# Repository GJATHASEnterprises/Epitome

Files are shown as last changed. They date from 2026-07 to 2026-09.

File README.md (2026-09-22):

# Epitome

**Charge everything. Touch nothing.**

[epitomecharge.com](https://epitomecharge.com)

---

## September 2026 lineup (canonical)

| Model | Price | Positioning | Enclosure | Lighting | MCU |
|---|---:|---|---|---|---|
| Step Walnut | $99 | Minimalist / wood-desk buyer | Black PETG base shell + wood-PLA top shell (sanded + Danish oil) | Single white status LED via 3 mm light pipe | Digispark-style ATtiny85 USB board |
| Step Obsidian | $109 | Gamer / battlestation buyer | Full CF-PETG (both shells) | WS2812B RGB glow lines, 8 LEDs per side (16 total) behind flush diffusers | Digispark-style ATtiny85 USB board |
| Outdoor Block Stone | $119 | Outdoor utility buyer | Sealed ASA body | Functional indicators only | Interlock controller |
| Outdoor Block Camo | $129 | Outdoor tactical aesthetic buyer | Sealed ASA body + camo finish | Functional indicators only | Interlock controller |

Notes (Sept-2026 planning estimates):
- Legacy material/process options were removed from the lineup.
- Customer pays shipping on all models.
- Step models include a 65W GaN brick, one 1 m USB-C input cable, and one USB-C output-device cable in-box.
- Step power configuration: 20W magnetic phone + up-to-15W second-device zone + 5W watch zone + 15W USB-C output (up to 60W total system claim).

## Source of truth docs

- `docs/launch-plan.md`
- `docs/technical-readouts/step-walnut.md`
- `docs/technical-readouts/step-obsidian.md`
- `docs/technical-readouts/outdoor-block-stone.md`
- `docs/technical-readouts/outdoor-block-camo.md`
- `docs/production-plan.md`
- `docs/budget-plan.md`
- `docs/marketing-plan.md`
- `docs/design-brief-step.md`
- `docs/assembly-guide.md`

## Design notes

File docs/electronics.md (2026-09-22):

# Epitome Step — Electronics Reference

Both models share the same beginner-friendly easy-connect electronics architecture. The only model differences are lighting hardware and the Obsidian rear mode button.

---

## Shared schematic overview

```
65W GaN brick
        │
        ▼
USB-C PD input receptacle (rear X=40)
        │
        ▼
PD input trigger board (20V negotiated input)
        │
        ▼
20V distribution PCB / block
        ├──→ 12V screw-terminal buck converter ──→ Qi2 20W TX (Zone 1)
        │                                      └──→ Qi TX up-to-15W (Zone 2)
        ├──→ 5V screw-terminal buck converter ──→ Watch TX coil (Zone 3)
        │                                      ├──→ Digispark-style ATtiny85 USB board
        │                                      └──→ Lighting harness
        └──→ USB-C PD 15W trigger board (rear output)
```

---

## Zone-by-zone power paths

### Zone 1 — Phone (Qi2 20W)
- Feed: 12V branch
- TX module: Qi2 20W magnetic module
- Protection: polyfuse (1.5A) + NTC + hardwired thermal cutoff
- Marketing language: "Qi2 magnetic charging — compatible with MagSafe-case iPhones and Qi2 Android phones"

### Zone 2 — Buds or second phone (up to 15W)
- Feed: **12V branch** (moved from 5V path)
- TX module: same $5.63 class TX as Zone 1 (non-magnetic placement)
- Protection: polyfuse (1.5A)
- Positioning language: "buds or a second phone — up to 15W"

### Zone 3 — Watch zone (5W)
- Feed: 5V branch
- TX: generic watch coil by default
- Important truth: generic watch coil does not charge Apple Watch without MFi-certified hardware

### USB-C output (rear)
- Trigger board: 15W-class output board
- Protection: polyfuse (~1A hold) + TVS diode
- Fuse basis: 15W at 20V is ~0.75A nominal

---

## Power budget (Sept-2026 planning)

| Load | Max power |
|---|---:|
| Zone 1 Qi2 TX | 20W |
| Zone 2 Qi TX | 15W |
| Zone 3 watch | 5W |
| USB-C output | 15W |
| ATtiny85 + lighting | ~1.5W |
| **Theoretical max** | **~56.5W** |
| **Marketing claim cap** | **Up to 60W total** |
| **Included brick** | **65W** |

The firmware soft cap is a detect-based heuristic only. When all zones are active, Zone 2 drops to a low-power profile. USB-C branch current is not directly measured by firmware.

---

## Safety systems

| System | Purpose |
|---|---|
| Polyfuse Zone 1 | Overcurrent protection on Zone 1 TX |
| NTC thermistor Zone 1 | Feeds TX thermal protection path |
| Thermal cutoff Zone 1 | Hard cutoff above thermal threshold |
| Polyfuse Zone 2 | Overcurrent on Zone 2 TX |
| Polyfuse Zone 3 | Overcurrent on watch coil |
| 1A hold polyfuse + TVS on USB-C output | Overcurrent + ESD on output branch |

---

## Hard sourcing and compliance rules

- All TX modules must have verifiable module-level FCC IDs.
- Battery module rules (UN38.3 + UL docs) apply to Outdoor Block gating before sourcing.

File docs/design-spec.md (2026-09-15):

# Epitome Step — Physical Design Specification (Sept 2026)

## Envelope targets

- Footprint and tier envelope are finalized from measured modules and CAD lock review.
- Use the measurement-order workflow and dimensional lock process defined in project planning docs before freezing STL/STEP outputs.
- Corner radii target: 6–8 mm external.

## Material split

| Part | Walnut | Obsidian |
|---|---|---|
| Base shell | Black PETG | CF-PETG |
| Top shell | Wood-PLA (oiled) | CF-PETG |
| Lighting | White light pipe status LED | Recessed WS2812B side glow lines |
| MCU | Digispark-style ATtiny85 USB board | Digispark-style ATtiny85 USB board |

## Hard constraints

- Coil window ≤1.5 mm above each TX coil.
- M3 insert bosses and wiring channels integrated into shell geometry.
- Rear USB-C input recess and strain-relief path required.

For dimensions and measurements to lock before final CAD, use `docs/design-brief-step.md`.

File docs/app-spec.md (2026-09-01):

# Epitome Step — Future Features (Batch 2+)

**No app in Batch 1.** The ATtiny85 in Batch 1 handles everything locally. No BLE, no Wi-Fi, no app.

This document captures ideas for future batches. Nothing here is on the roadmap yet.

---

## Why no app in Batch 1

1. **Complexity kills Batch 1.** Adding app connectivity (ESP32, BLE pairing, iOS app) would double the electronics cost and triple the firmware work. Not justified for 10 units.
2. **Most users don't want an app for a charger.** Plug in and charge. The simpler it is, the better the product.
3. **The ATtiny85 is sufficient.** LED control, night mode, soft cap — all done without any wireless.

---

## Future ideas — Obsidian RGB app control

If there's demand for it, the Obsidian model could add a BLE module (ESP32-C3 or nRF52840) to allow app-based colour control:

- Choose any colour, not just the 8 presets
- Schedule night mode to actual clock time
- Per-zone LED brightness (e.g. dim Zone 2 if no buds detected)
- RGB mode sync with music (requires phone microphone access — complicated)

This would require replacing the ATtiny85 with a more capable MCU and adding a BLE antenna. Estimated additional cost: $4–6 per unit.

---

## Future ideas — zone scheduling

- Set specific zones to turn on/off at set times (e.g., disable Zone 1 phone charging after midnight)
- Use BLE-synced real-time clock instead of ATtiny85 timer

---

## Future ideas — zone toggles

- Physical or app-controlled toggle to disable a zone
- Useful for power management if user only has phone + watch (disable Zone 2)

---

## What to do before building any of this

1. Finish Batch 1 and ship it
2. Ask customers if they want an app
3. If > 50% say yes, prototype a BLE version for Batch 3
4. Keep Walnut as app-free — the Walnut buyer does not want an app for their charger

---

## What is explicitly NOT planned

- Voice control (Alexa/Google — unnecessary complexity)
- USB data transfer (charging only — USB-C ports are power-only PD)
- Display / screen on dock (adds cost, adds failure mode)
- Battery / UPS mode (too complex, too expensive)
- Laptop Qi charging (not in Qi/Qi2 spec at useful wattage)

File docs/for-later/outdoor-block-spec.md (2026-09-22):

# Epitome Outdoor Block — Concept Spec (FOR LATER)

**Status:** Concept. Gated behind Step Batch 1 success + reserve gate.

## Models and pricing

| Model | Price | Positioning |
|---|---:|---|
| Outdoor Block Stone | $119 | rugged neutral finish |
| Outdoor Block Camo | $129 | rugged camo finish |

## Tariffed BOM alignment (Sept 2026)

All China-sourced electronics use 25% Section 301 pricing. Reference: `docs/technical-readouts/outdoor-block-stone.md` and `docs/technical-readouts/outdoor-block-camo.md`.

| Part | Tariffed cost |
|---|---:|
| Certified 20,000 mAh PD bank | $22.50 |
| 20W magnetic phone TX | $7.50 |
| Zone 2 Qi TX module (up-to-15W class) | $5.63 |
| IP67 panel USB-C + cap | $4.00 |
| Interlock + sensors + harness | $7.30 |
| ASA/TPU enclosure + hardware | $8.00 |
| Camo process adder (Camo only) | $3.50 |
| Packaging/consumables | $0.50 |

Resulting build targets:
- **Stone:** ~$53.30 → net ~ $34/sale at $119
- **Camo:** ~$56.80 → net ~ $39/sale at $129

## Gates before spending reserve

- [ ] Step Batch 1 sold through (≥3 paid units)
- [ ] LLC + product liability insurance active
- [ ] Certified battery module source confirmed
- [ ] Prototype passes immersion/drop/thermal/runtime/interlock gates

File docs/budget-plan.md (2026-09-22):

# Epitome — Budget Plan (Sept 2026 planning estimates)

## Capital constraint

- Total available capital now: **~$2,000**.
- Operating rule: phase-gated launch from `docs/launch-plan.md` (demand-first, compliance-second, inventory-last).

## Startup costs (Step launch envelope)

These costs were missing from older parts-only planning and must be tracked up front:

| Startup item | Estimate | Notes |
|---|---:|---|
| FCC testing (good path with verifiable module FCC IDs) | ~$1,000–2,500 | Step Walnut + Obsidian share one test path |
| LLC formation | ~$50–150 | Must be active before selling |
| Year-1 general/product liability insurance | ~$500–1,050 | Range varies by carrier and disclosures |
| **Startup subtotal (compliance + legal + insurance)** | **~$1,550–3,700** | |

## Step launch total envelope

| Bucket | Estimate |
|---|---:|
| Prototype + tooling + CAD + measurement-order work | ~$800–900 |
| Startup subtotal (above) | ~$1,550–3,700 |
| **Total Step launch envelope** | **~$2,350–4,600** |

Because current capital is ~$2,000, execution must stay phase-gated and stop at each gate until funding and demand conditions are met.

## Unit economics reference (net-after-fees)

| Product | Build cost | Price | Net-after-fees |
|---|---:|---:|---:|
| Step Walnut | ~$48.63 | $99 | ~ $30–32/sale |
| Step Obsidian | ~$54.63 | $109 | ~ $34–38/sale |
| Outdoor Block Stone (gated) | ~$53.30 | $119 | ~ $34/sale |
| Outdoor Block Camo (gated) | ~$56.80 | $129 | ~ $39/sale |

## Hard sourcing gates

- Every TX module must have a verifiable module-level FCC ID.
- Outdoor Block battery modules must have verifiable UN38.3 and UL component docs.

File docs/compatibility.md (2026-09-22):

# Epitome Step — Device Compatibility

---

## Zone 1 — Phone (Qi2 magnetic, up to 20W)

| Device | Compatible | Notes |
|---|---|---|
| iPhone 13 and newer (with MagSafe-compatible case) | ✅ | Qi2 magnetic alignment |
| Qi2-enabled Android phones | ✅ | Qi2 alignment where supported |
| Other Qi-enabled phones | ✅ | Standard Qi fallback |

---

## Zone 2 — Buds / second phone (plain Qi, up to 15W)

| Device | Compatible | Notes |
|---|---|---|
| AirPods / Galaxy Buds / Pixel Buds (Qi case models) | ✅ | Typical draw is 2–5W |
| Qi-enabled second phone | ✅ | Non-magnetic placement |
| Non-Qi accessories | ❌ | Requires Qi receiver |

---

## Zone 3 — Watch zone

| Device | Compatible | Notes |
|---|---|---|
| Generic Qi watch devices | ✅ | With generic coil option |
| Apple Watch | ❌ by default | Requires separate MFi-certified module option |

Do not market Apple Watch support unless the MFi option is selected.

---

## USB-C output (rear)

| Port | Protocol | Compatible devices |
|---|---|---|
| USB-C output (15W) | USB-C PD class output | Phones, earbuds cases, small accessories, speakers |

In-box cables: 1 input cable + 1 output-device cable.

---

## Wording compliance

- Use: "Qi2 magnetic charging — compatible with MagSafe-case iPhones and Qi2 Android phones."
- Use: "up to 60W total."
- Avoid bare "MagSafe" as a standalone product claim.

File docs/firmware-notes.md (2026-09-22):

# Epitome Step — Firmware Notes (Digispark ATtiny85)

No ESP32. No BLE. No app. The Digispark-style ATtiny85 board handles LED control, heuristic load behavior, and night mode.

---

## Soft-cap context

The documented product-level claim is **"up to 60W total"**.

Current firmware is still detect-based:
- Zone 1 active estimate: +20W
- Zone 2 active estimate: up to +15W
- Zone 3 active estimate: +5W
- Lighting budget: up to ~1.5W
- USB-C output path is 15W-class, but firmware does not directly measure branch current.

When all zones are active, firmware shifts Zone 2 to a low-power profile. This is a heuristic behavior, not a measured closed-loop power controller.

---

## Watch-zone note

Default generic watch-coil path is not Apple Watch-compatible. Do not claim Apple Watch support in firmware-linked product docs unless MFi hardware is selected.

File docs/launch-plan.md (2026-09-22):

# Epitome — Master Launch Plan (Sept-2026 planning estimates)

This is the operating plan for launching Epitome with a hard capital limit of about **$2,000**.

## Core rules

- Total available capital: **~$2,000**.
- Every phase must fit inside that limit.
- Follow this order: **demand first, compliance second, inventory last**.
- Do **not** build sellable inventory before demand is proven and FCC authorization is complete.
- FCC rule reminder: advertising an unauthorized RF product as "for sale" is a violation. Waitlist pages must not take money or claim active sales.

## Phase 0 — Free verification week (~$0)

1. Ask Qi/Qi2 TX module vendors for module-level FCC IDs.
2. Verify each ID at: https://www.fcc.gov/oet/ea/fccid.
3. Ask the battery module vendor for UN38.3 + UL component docs for the future Outdoor Block.
4. Verify those battery docs directly with the issuing lab.
5. Request quotes from **3 FCC-recognized labs**.
6. Note in all quote requests: one FCC Step test covers both Walnut and Obsidian because electronics are identical; Stone and Camo can share one later test.

**Why this matters:**
- These free answers decide whether the near-term compliance bill lands around **~$1,000–1,500** (good path) or **~$4,000+** (bad path).

### Gate 0 → 1
Do not move to Phase 1 until these vendor and lab answers are documented.

## Phase 1 — Prototype + demand test (~$500–700)

1. Place a measurement order (~$35): one of each module from current docs.
2. Build only **2 prototypes total** (1 Walnut + 1 Obsidian), not 6.
3. Buy only essential setup/tooling (~$120).
4. Form LLC (~$50–150) before any selling activity.
5. Publish a free landing page + waitlist with prototype/renders.
6. Share in relevant communities (r/battlestations, r/functionalprint, etc.).
7. Waitlist page rules: no payments, no "for sale" claims.

### Gate 1 → 2
Move forward only if:
- Waitlist interest is meaningful (suggested threshold: **~100 signups**), **and**
- FCC quote path from Phase 0 remains favorable.

If demand is weak, pause. A max loss of about ~$700 means the demand test worked.

## Phase 2 — Compliance (~$1,000–2,500 if Phase 0 is favorable)

1. Run FCC verification testing for the Step platform (single test covering Walnut + Obsidian).
2. Activate year-1 general/product liability insurance (~$500–1,500).

### Gate 2 → 3
Do not proceed until FCC authorization is in hand.

## Phase 3 — Pre-order-funded production

1. Open paid pre-orders only after Phase 2 gate passes.
2. Build only what is sold.
3. Keep direct sales on own site (customer pays shipping) to avoid typical marketplace fees (~8–15% vs ~3% direct processing).

Sept-2026 planning economics after current Step optimizations:
- **Walnut build:** ~$48.63 → net about **$30–32** at $99.
- **Obsidian build:** ~$54.63 → net about **$34–38** at $109.

Compliance is a one-time toll; after prototypes, each additional unit is mostly BOM cost.

## Phase 4 — Outdoor Block (gated sequence, not cancelled)

Block remains gated until either:
- Step cumulative profit reaches **~$3,000**, or
- Block waitlist/pre-order interest reaches **~40 signups**.

Compliance floor (good path):
- **~$1,500–3,000** with FCC-ID'd modules + certified battery module docs + final FCC verification.
- Full UL 2056 end-product listing (~$15,000–30,000) is a **later scaling milestone** for Amazon/big retail, not required for legal direct sales.

Quality/failure-margin guidance:
- Keep **10–15% defect reserve**.
- Budget **1 sacrificial QC unit per batch** for destructive validation.
- Follow existing QC: immersion, 6-face drop, 25-cycle battery tests.

Li-ion shipping rules for Block:
- Ground only.
- UN3481.
- Battery installed in equipment.
- ≤100Wh (74Wh module qualifies).

## Risk register (plain-language)

1. **Cheap 65W brick risk**: the $9.50 target only stands if genuine UL/ETL/FCC docs check out and thermal-soak samples pass. If not, fall back to the $13.75 brick.
2. **Zone 2 geometry risk**: second phone/buds landing area must be validated in CAD before STL freeze.
3. **Dual-load thermal risk**: test Zone 1 + Zone 2 + USB-C use for hot spots and stability.
4. **Soft-cap firmware limitation**: current cap is heuristic detect-based behavior; no direct current measurement.
5. **Watch-zone compatibility risk**: generic watch coils do not charge Apple Watch without MFi hardware.
6. **Marketing wording risk**:
   - Say: "up to 60W total".
   - Say: "Qi2 magnetic charging — compatible with MagSafe-case iPhones".
   - Do not use bare "MagSafe" as a product claim.
   - Say: "IP67 — submersion-safe in shallow water".
   - Do not use unqualified "waterproof".

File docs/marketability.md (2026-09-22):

# Epitome Step — Market Positioning (Sept 2026 planning estimates)

## SKU narrative

| Model | Price | Buyer | Why it converts |
|---|---:|---|---|
| Step Walnut | $99 | Minimalist / wood-desk setups | Warm material story + clean status light |
| Step Obsidian | $109 | Gamer / battlestation setups | Matte carbon + RGB glow-line identity |

## Economics fit

- Walnut net: ~ $30–32/sale
- Obsidian net: ~ $34–38/sale
- Shipping is customer-paid; checkout clarity is part of conversion strategy.

## Message strategy

- Walnut copy: “minimal, warm, desk-first”.
- Obsidian copy: “dark battlestation, configurable RGB glow”.
- Technical trust language:
  - “Qi2 magnetic charging — compatible with MagSafe-case iPhones and Qi2 Android phones.”
  - “Up to 60W total.”
  - “Buds or second phone on Zone 2 (up to 15W, non-magnetic).”

## Watch-zone honesty requirement

- Generic watch coils do not charge Apple Watch.
- Do not depict Apple Watch charging unless an MFi module is selected.

For full cost stack and test gates, see `docs/production-plan.md` and `docs/technical-readouts/`.

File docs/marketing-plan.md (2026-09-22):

# Epitome — Marketing Plan (Sept 2026 planning estimates)

**Budget target: ~$400 paid marketing.** No paid spend until prototype photos and compliant launch wording are ready.

## Positioning

- **Step Walnut ($99):** minimalist / wood-desk buyer, warm premium aesthetic.
- **Step Obsidian ($109):** gamer / battlestation buyer, matte carbon + RGB glow-line identity.

## Channel allocation (~$400)

| Channel | Budget | Notes |
|---|---:|---|
| Etsy Ads (Walnut-led search terms) | $150 | Start low; kill if no traction |
| Meta/Instagram retargeting + short reels | $140 | Focus on creator-style demos |
| 2 gifted units to micro setup creators | ~$80 | Content + trust-building |
| Photo props/backdrop | $30 | Keep lean |
| **Reserve** | remainder | Includes trimmed Reddit test budget |

## Message guardrails

- Use: “Qi2 magnetic charging — compatible with MagSafe-case iPhones and Qi2 Android phones.”
- Use: “up to 60W total.”
- Use: “Zone 2 supports buds or a second phone (up to 15W, non-magnetic).”
- Do not use bare “MagSafe” as a product claim.
- Do not show Apple Watch in watch-zone visuals unless MFi hardware is selected.
- Never claim a product is for sale before FCC authorization is complete.

## Shipping note

Customer pays shipping. Run A/B copy tests only after compliance gates are met.

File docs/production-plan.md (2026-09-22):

# Epitome — Production Plan (Sept 2026 planning estimates)

## 1) Product lineup and build materials

- **Step Walnut ($99):** minimalist / wood-desk buyer. Black PETG base + wood-PLA top. Digispark-style ATtiny85. Single white status LED.
- **Step Obsidian ($109):** gamer / battlestation buyer. Full CF-PETG shells. Digispark-style ATtiny85. WS2812B RGB glow lines.
- **Outdoor Block Stone ($119) / Camo ($129):** 20W magnetic phone + 5–10W buds + 20W USB-C output (Batch 2 gated).

Authoritative per-model BOMs and QC gates live in `docs/technical-readouts/`.

## 2) Unit economics (customer pays shipping)

| Model | Build cost | Price | Net after fees/processing/defect reserve |
|---|---:|---:|---:|
| Step Walnut | ~$48.63 | $99 | ~ $30–32 / sale |
| Step Obsidian | ~$54.63 | $109 | ~ $34–38 / sale |
| Outdoor Block Stone | ~$53.30 | $119 | ~ $34 / sale |
| Outdoor Block Camo | ~$56.80 | $129 | ~ $39 / sale |

## 3) Sept-2026 tariffed reference prices (25% Section 301 on China-sourced electronics)

- Step Zone 1 TX: **$5.63**
- Step Zone 2 TX (same SKU class): **$5.63**
- Watch TX coil (generic): **$3.50 estimate**
- Step USB-C output trigger board (15W class): **$1.50**
- Step 65W GaN brick target: **$9.50** *(fallback $13.75 if cert docs fail checks)*
- Step cables (1 input + 1 output): **$3.00**
- Outdoor Block 20W magnetic TX: **$7.50**
- Outdoor Block IP67 USB-C: **$4.00**
- Outdoor Block 20,000 mAh certified PD bank: **$22.50**

## 4) Compliance and sourcing rules

- Every wireless TX module must have a verifiable module-level FCC ID.
- Outdoor Block battery modules must provide verifiable UN38.3 and UL component docs.
- Step Walnut + Obsidian share one FCC test path because electronics are identical.
- Outdoor Block Stone + Camo also share one test path later because electronics are identical.

## 5) Build sequence rules

- Do not build sellable inventory before demand is proven and FCC authorization is complete.
- Waitlist can be used before authorization, but must not collect payment or claim live sales.
- Operating gates and phase order are defined in `docs/launch-plan.md`.

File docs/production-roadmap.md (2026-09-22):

# Epitome — Production Roadmap (Sept 2026 planning estimates)

## Phase 0 — Free verification week (~$0)

- Verify FCC IDs for all candidate TX modules.
- Verify UN38.3 + UL component docs for Outdoor Block battery module.
- Collect 3 FCC-lab quotes.

Gate: do not continue until this verification package is complete.

## Phase 1 — Prototype + demand test (~$500–700)

- Build only 2 Step prototypes total: 1 Walnut + 1 Obsidian.
- Keep tooling essentials to about ~$120.
- Launch a free waitlist page (no payments, no "for sale" claims).

Gate: continue only if waitlist interest is meaningful (~100 signups suggested) and FCC quote path is favorable.

## Phase 2 — Compliance (~$1,000–2,500 good path)

- Run Step FCC authorization path.
- Activate year-1 general/product liability insurance.

Gate: FCC authorization must be in hand before paid pre-orders.

## Phase 3 — Pre-order-funded production

- Take paid orders only after compliance gate.
- Build only what is sold.
- Direct sales first to preserve margin.

## Phase 4 — Outdoor Block (gated)

- Keep Block gated until Step cumulative profit reaches ~$3,000 or Block waitlist/pre-order demand reaches ~40 signups.
- Good-path Block compliance floor: ~$1,500–3,000 with FCC-ID modules + certified battery docs + final verification.
- Full UL 2056 listing (~$15,000–30,000) is a later distribution milestone, not a launch requirement for legal direct sales.

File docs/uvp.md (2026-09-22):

# Epitome Step — Unique Value Proposition (Sept 2026 planning estimates)

## Positioning

- **Step Walnut ($99):** minimalist, warm desk aesthetic.
- **Step Obsidian ($109):** gamer battlestation aesthetic with RGB glow lines.

Both use the same charging architecture and include a 65W GaN brick, one USB-C input cable, and one USB-C output cable.

## Why it works

1. Distinct buyer fit instead of one compromise design.
2. Premium-looking materials at accessible pricing.
3. Practical charging setup: 20W magnetic phone, up-to-15W second zone, 5W watch zone, and 15W USB-C output.

## Product identity

- Walnut: black PETG base + wood-PLA top, sanded and oiled, single white status LED.
- Obsidian: full CF-PETG shell, WS2812B side glow lines, Digispark-style ATtiny85 USB mode control.

## Compliance and wording guardrails

- Use: "Qi2 magnetic charging — compatible with MagSafe-case iPhones and Qi2 Android phones."
- Do not use bare "MagSafe" as a product claim.
- Watch-zone decision remains open: MFi module, explicit non-Apple-Watch positioning, or remove watch zone.

For exact BOM/economics/QC, use `docs/technical-readouts/`.

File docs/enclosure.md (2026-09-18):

# Epitome Step — Enclosure Specification (Sept 2026)

## Material baseline

| Model | Base shell | Top shell |
|---|---|---|
| Step Walnut | Black PETG | Wood-PLA (sanded + Danish oil) |
| Step Obsidian | CF-PETG | CF-PETG |

Legacy enclosure material/process options are removed from this plan.

## Shared mechanical constraints

- Three-tier stepped body.
- Wall thickness target: 2.4 mm.
- Coil window thickness: ≤1.5 mm.
- M3 heat-set inserts ×4.
- Rear USB-C recess + strain-relief channel.

## Obsidian lighting geometry

- Recessed side grooves with flush diffuser bars.
- WS2812B 8 LEDs per side (16 total).
- Glow lines only (LED dots not directly visible).

## CAD source of truth

- Dimensional capture workflow: `docs/design-brief-step.md` §5.
- Production build details: `docs/technical-readouts/step-walnut.md` and `docs/technical-readouts/step-obsidian.md`.

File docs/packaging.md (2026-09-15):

# Epitome Step — Packaging Specification (Sept 2026)

## In-box policy (Step models)

- Include **1× 65W GaN brick**, **one 1 m USB-C cable for the power-input port**, and **2× USB-C device cables for the two output ports**.
- Customer pays shipping at checkout.

## Packaging cost target

| Item | Unit cost |
|---|---:|
| Kraft box + protective insert + printed card | $3.00 |

## Notes

- Keep labeling model-specific (Walnut vs Obsidian).
- Keep claims aligned with technical readouts.
- Full per-model economics are in `docs/technical-readouts/`.

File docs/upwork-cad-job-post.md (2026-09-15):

# Upwork Job Post — CAD Production Files for Epitome Step

**Copy-paste everything below the line into Upwork. Budget: fixed price $250 (accept range $150–350).**

---

## Title
CAD production files (STEP/STL) for a 2-piece 3D-printed three-tier wireless charger enclosure — full written spec provided

## Category
CAD & 3D Modeling → Product Design (Fusion 360 / SolidWorks / Onshape)

## Description

I'm building a three-tier desktop wireless charging stand ("Epitome Step") sold in two material variants that share identical geometry. It has dedicated zones for a phone, earbuds, and watch, with the top watch step set back from the front. I need production-ready CAD from a **complete written design brief** — the industrial design direction, target envelope dimensions, all engineering constraints, and caliper-measured component dimensions are already documented. This is a modeling job, not a design-from-scratch job: the added printability note and coil-pocket fit coupons are just low-cost print-validation deliverables to reduce revision rounds.

**You will receive:**
- A detailed design brief (target envelope 165 × 100 mm, three-tier layout, wall thicknesses, coil pocket rules, insert boss specs, FDM printability constraints)
- Repo-generated renders / technical diagrams showing the intended three-tier structure and proportions
- Caliper-measured dimensions for every internal component (coils, PCBs, inserts, light pipe / LED strips, Digispark board, screw-terminal distribution parts)
- Reference sketches of the intended look

**Deliverables:**
1. Parametric CAD (Fusion 360 preferred; native file + STEP)
2. STL exports, print-oriented, for both shells × both variants:
   - Variant A ("Walnut"): base + top shell with Ø3.2 mm front light-pipe hole
   - Variant B ("Obsidian"): base + top shell with recessed side grooves (5 × 3 × ~140 mm) for LED diffuser bars, incl. printable diffuser bar model
3. Parametric clearance variables / notes for fit tuning, including per-material offsets for PETG, wood-PLA, and CF-PETG shrinkage
4. Dimensioned drawing PDF (top, front, side, section through all three coil pockets)
5. Short printability report: part orientation, support-free confirmation, estimated print time/material per shell
6. Milestone 2 test-fit artifacts: one small coil-pocket fit coupon STL for each coil pocket (phone / earbuds / watch)
7. Exploded-view image showing assembly stack order

**Hard requirements (all specified in the brief):**
- Wall 2.4 mm; ≤1.5 mm directly above coil pockets
- Coil pockets sized from provided measurements + 0.3 mm clearance
- 4× M3 heat-set boss (Ø7.2 mm hole / Ø10 mm boss); no fasteners visible from top/sides
- Rear face has **3× USB-C ports total**: 1× differentiated USB-C PD **IN** plus 2× USB-C PD outputs; include the rear recess/strain channel for the USB-C input plug overmold, plus thermistor groove and board standoffs
- Three coil pockets total, including the watch pocket on the set-back Step 3 tier
- No barrel jack anywhere on the rear face; the USB-C **IN** port must be differentiated with either a deeper recess or engraved **IN** marking
- Both shells FDM-printable without supports (no overhangs >50° without chamfer)

**Process & milestones:**
- Milestone 1 (30%): exterior form model for approval — visually matches the repo-generated renders/technical diagrams and the brief's §2 envelope within ±10%
- Milestone 2 (70%): full internal features, all deliverables. Includes **2 revision rounds** (e.g., pocket fit adjustments after my test print), plus the three coil-pocket fit coupon STLs
- Timeline: 7–10 days preferred

## Printer / fabrication info

**To be provided to the hired freelancer before final modeling starts:**
- Printer bed size
- Nozzle size(s)
- Exact PETG / wood-PLA / CF-PETG material brands
- Preferred layer height / wall settings if they affect fit allowances

Until those fabrication inputs are supplied, the requested clearance variables, printability notes, and fit-coupon STLs should be treated as **provisional print-validation deliverables** rather than final locked values.

**To apply:** share 1–2 examples of enclosure/consumer-product CAD you've modeled for FDM printing, and confirm you can deliver native Fusion 360 (or state your tool).

---

## Internal notes (not part of the post)

- **Do NOT post until §5 of `design-brief-step.md` is filled in with caliper measurements** — posting before parts arrive invites guesswork and a wasted revision round.
- Send shortlisted applicants the design brief only (not the whole repo — pricing/margin docs are private).
- Scope is the **three-tier** Step enclosure only: phone + earbuds + watch, target footprint 165 × 100 mm, watch step setback preserved, exterior shape still TBD within the brief envelope.
- Screen for: FDM experience specifically (injection-molding-only folks over-design), asks about tolerances/test prints (good sign), portfolio with visible layer-line-aware design.
- Red flags: bids >$500 for this scope, "I will design your product" language (scope creep), no questions asked before bidding.
- Budget source: reallocated from marketing (see budget-plan.md). Cap: $350 including revisions.
- Payment: milestones via Upwork escrow only, no off-platform payment.

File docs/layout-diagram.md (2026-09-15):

# Epitome Step — Layout Diagrams (Sept 2026)

Geometry workflow and dimensional locking now live in:
- `docs/design-spec.md`
- `docs/production-plan.md`

Model identity callouts:
- Walnut: black PETG base + wood-PLA top, white status light pipe.
- Obsidian: full CF-PETG shell, WS2812B side glow lines (8 LEDs per side, 16 total), Digispark-style ATtiny85 USB control.

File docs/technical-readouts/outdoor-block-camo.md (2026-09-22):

# Outdoor Block Camo — Technical Readout

## Enclosure specification
- Sealed ASA body targeting IP67 ingress performance.
- Finish stack: OD-green ASA base, masked spray camo pattern, UV matte clear coat.
- Gasket: 2 mm TPU printed gasket in perimeter groove.
- Closure hardware: M3 stainless screws ×8, cross-pattern torque sequence.
- Porting: membrane pressure vent and IP67 panel-mount USB-C with tethered TPU cap.

## Electronics BOM (Sept 2026 planning estimates, tariffed where applicable)
| Item | Unit cost |
|---|---:|
| Certified 20,000 mAh (74 Wh) PD battery module (China, +25% tariff) | $22.50 |
| 20W magnetic phone TX module (China, +25% tariff) | $7.50 |
| 5–10W buds TX module (China, +25% tariff) | $2.50 |
| USB-C PD output path (20W) + interlock control hardware | $4.50 |
| NTC on cell + NTC on phone coil + fused harness | $2.80 |
| IP67 panel-mount USB-C + tethered cap (China, +25% tariff) | $4.00 |
| Membrane vent | $1.00 |
| ASA + TPU enclosure materials and hardware | $8.00 |
| Camo finish process adder | $3.50 |
| Packaging and consumables | $0.50 |
| **Build cost** | **$56.80** |

## Firmware behavior
- Interlock: USB-C insertion disables buds charging zone within 1 second.
- Interlock restore: buds zone re-enabled on USB-C removal.
- Battery protection: if bank <10%, all zones disabled.
- LED behavior: fuel-gauge blink patterns plus low-battery cutoff indication.

## Power budget
- Battery system: 74 Wh certified module.
- Phone zone: up to 20W magnetic TX.
- Buds zone: 5–10W.
- USB-C PD output: **20W**.

## Compliance + launch gating
- Batch launch is gated by `docs/launch-plan.md` Phase 4.
- Compliance floor target: **~$1,500–3,000** when using FCC-ID'd TX modules and verified UN38.3/UL battery component docs.
- Full UL 2056 end-product listing (~$15,000–30,000) is a later distribution milestone, not required for legal direct sales.
- Hard sourcing requirement: verify module FCC IDs and battery UN38.3/UL docs before ordering production lots.

## Shipping constraints
- Ground-only shipping.
- UN3481 labeling.
- Battery installed in equipment.
- ≤100Wh per unit (74Wh module qualifies).

## QC checklist
- [ ] All Step-model QC gates (charge compatibility, thermal soak, cutoff simulation, no-brownout, cosmetic, shake).
- [ ] USB-C interlock disable/restore timing validation.
- [ ] 30-minute immersion at 30 cm with desiccant telltale pass.
- [ ] 1 m drop test, 6 faces, post-test full functionality.
- [ ] Measured runtime ≥2.5 full phone charges.
- [ ] 25-cycle battery validation.
- [ ] Wording compliance: use “IP67 — submersion-safe in shallow water”; avoid unqualified “waterproof”.

## Unit economics
- Build cost: ~$56.80.
- Customer-paid shipping required (ground service for Li-ion).
- Net per sale at $129: approximately $39.

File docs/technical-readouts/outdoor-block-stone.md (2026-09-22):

# Outdoor Block Stone — Technical Readout

## Enclosure specification
- Sealed ASA body targeting IP67 ingress performance.
- Finish: gray ASA (no camo paint process).
- Gasket: 2 mm TPU printed gasket in perimeter groove.
- Closure hardware: M3 stainless screws ×8, cross-pattern torque sequence.
- Porting: membrane pressure vent and IP67 panel-mount USB-C with tethered TPU cap.

## Electronics BOM (Sept 2026 planning estimates, tariffed where applicable)
| Item | Unit cost |
|---|---:|
| Certified 20,000 mAh (74 Wh) PD battery module (China, +25% tariff) | $22.50 |
| 20W magnetic phone TX module (China, +25% tariff) | $7.50 |
| 5–10W buds TX module (China, +25% tariff) | $2.50 |
| USB-C PD output path (20W) + interlock control hardware | $4.50 |
| NTC on cell + NTC on phone coil + fused harness | $2.80 |
| IP67 panel-mount USB-C + tethered cap (China, +25% tariff) | $4.00 |
| Membrane vent | $1.00 |
| ASA + TPU enclosure materials and hardware | $8.00 |
| Stone finish process adder | $0.00 |
| Packaging and consumables | $0.50 |
| **Build cost** | **$53.30** |

## Firmware behavior
- Interlock: USB-C insertion disables buds charging zone within 1 second.
- Interlock restore: buds zone re-enabled on USB-C removal.
- Battery protection: if bank <10%, all zones disabled.
- LED behavior: fuel-gauge blink patterns plus low-battery cutoff indication.

## Power budget
- Battery system: 74 Wh certified module.
- Phone zone: up to 20W magnetic TX.
- Buds zone: 5–10W.
- USB-C PD output: **20W**.

## Compliance + launch gating
- Batch launch is gated by `docs/launch-plan.md` Phase 4.
- Compliance floor target: **~$1,500–3,000** when using FCC-ID'd TX modules and verified UN38.3/UL battery component docs.
- Full UL 2056 end-product listing (~$15,000–30,000) is a later distribution milestone, not required for legal direct sales.
- Hard sourcing requirement: verify module FCC IDs and battery UN38.3/UL docs before ordering production lots.

## Shipping constraints
- Ground-only shipping.
- UN3481 labeling.
- Battery installed in equipment.
- ≤100Wh per unit (74Wh module qualifies).

## QC checklist
- [ ] All Step-model QC gates (charge compatibility, thermal soak, cutoff simulation, no-brownout, cosmetic, shake).
- [ ] USB-C interlock disable/restore timing validation.
- [ ] 30-minute immersion at 30 cm with desiccant telltale pass.
- [ ] 1 m drop test, 6 faces, post-test full functionality.
- [ ] Measured runtime ≥2.5 full phone charges.
- [ ] 25-cycle battery validation.
- [ ] Wording compliance: use “IP67 — submersion-safe in shallow water”; avoid unqualified “waterproof”.

## Unit economics
- Build cost: ~$53.30.
- Customer-paid shipping required (ground service for Li-ion).
- Net per sale at $119: approximately $34.

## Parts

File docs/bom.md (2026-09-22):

# Epitome — BOM & Economics Snapshot (Sept 2026 planning estimates)

Canonical detailed BOMs are in `docs/technical-readouts/`.

## Tariffed key part prices (China-sourced electronics, +25%)

| Part | Price |
|---|---:|
| Qi2 / Qi TX module (used for Zone 1 and Zone 2 on Step) | $5.63 |
| Watch TX coil (generic) | $3.50 *(estimate; pending sourcing)* |
| USB-C trigger board (Step output, 15W class) | $1.50 |
| 65W GaN brick (Step models, budget source target) | $9.50 |
| 65W GaN brick fallback price (if cert docs fail review) | $13.75 |
| USB-C cable (Step models, two cables total) | $3.00 |
| 20W magnetic TX (Outdoor Block) | $7.50 |
| IP67 USB-C (Outdoor Block) | $4.00 |
| 20,000 mAh certified PD bank | $22.50 |

## Enclosure + packaging cost targets

| Item | Cost |
|---|---:|
| Walnut enclosure (black PETG base + wood-PLA top + oil) | $9.50 |
| Obsidian enclosure (CF-PETG shells incl. premium) | $11.07 |
| Kraft packaging box set | $3.00 |

## Hard sourcing rules

- All wireless TX modules must have verifiable module-level FCC IDs.
- Outdoor Block battery modules must have verifiable UN38.3 and UL component documentation.

## Model economics (net-after-fees)

| Model | Build cost | Price | Net-after-fees |
|---|---:|---:|---:|
| Step Walnut | ~$48.63 | $99 | ~ $30–32/sale |
| Step Obsidian | ~$54.63 | $109 | ~ $34–38/sale |
| Outdoor Block Stone | ~$53.30 | $119 | ~ $34/sale |
| Outdoor Block Camo | ~$56.80 | $129 | ~ $39/sale |

## Watch-zone compatibility note

The generic ~$3.50 watch coil does **not** support Apple Watch (Apple uses a proprietary protocol). Open decision:
1. Add MFi module (+$8–11),
2. Keep generic coil and clearly state "not compatible with Apple Watch", or
3. Drop Zone 3 on Step.

Do not show Apple Watch in Step watch-zone marketing unless option 1 is selected.

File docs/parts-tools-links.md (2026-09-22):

# Epitome Step — Parts, Tools, and Supplier Links (Sept 2026 planning estimates)

## Tariffed key electronics (reference pricing)

| Part | Target price |
|---|---:|
| Zone 1 Qi2 TX module | $5.63 |
| Zone 2 Qi TX module (up-to-15W class) | $5.63 |
| USB-C 15W output trigger board | $1.50 |
| 65W GaN brick (budget-source target) | $9.50 |
| 65W GaN brick fallback | $13.75 |
| USB-C cables (input + output pair) | $3.00 |
| Obsidian RGB LEDs (WS2812B) | see readout allowances |

## Sourcing rules

- Buy only TX modules with verifiable module-level FCC IDs.
- For Outdoor Block, buy only battery modules with verifiable UN38.3 and UL component docs.

## Enclosure materials

| Part | Notes |
|---|---|
| Black PETG | Walnut base shell |
| Wood-PLA filament | Walnut top shell, oil-finished |
| CF-PETG filament | Obsidian base/top shells |
| ASA + TPU | Outdoor Block shells + gasket (gated) |

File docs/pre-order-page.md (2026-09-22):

# Epitome Step — Pre-Order Page Copy (Sept 2026 planning estimates)

## STEP WALNUT — $99

**The minimalist desk charger that still looks like furniture.**

- Black PETG base shell + wood-PLA top shell
- Sanded + Danish-oiled finish
- Single white status LED via light pipe
- Charging stack: 20W magnetic phone + up-to-15W second-device zone + 5W watch + 15W USB-C output
- Includes 65W GaN brick + 2 USB-C cables (1 input + 1 output-device)
- Customer pays shipping at checkout

## STEP OBSIDIAN — $109

**Built for dark battlestations, with clean RGB glow lines.**

- Full CF-PETG shells (carbon-weave matte)
- WS2812B side RGB grooves with flush diffuser bars (no visible dots)
- Digispark-style ATtiny85 RGB modes with rear-button control
- RGB brightness auto-capped under full wireless load
- Charging stack: 20W magnetic phone + up-to-15W second-device zone + 5W watch + 15W USB-C output
- Includes 65W GaN brick + 2 USB-C cables (1 input + 1 output-device)
- Customer pays shipping at checkout

## Shared checkout language

- “Qi2 magnetic charging — compatible with MagSafe-case iPhones and Qi2 Android phones.”
- “Up to 60W total.”
- “Ships in small batches after QC.”
- “Watch zone uses a generic watch coil and is not compatible with Apple Watch unless the MFi option is selected.”

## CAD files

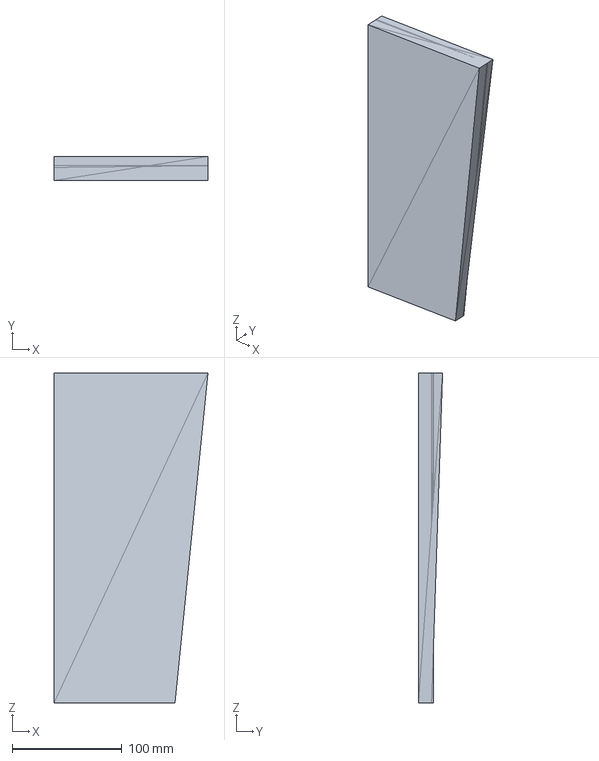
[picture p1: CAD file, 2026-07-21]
assets/export/quad-dock-full.step
140.0 x 22.0 x 300.0 mm

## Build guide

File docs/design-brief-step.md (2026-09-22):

# Epitome Step — Design Brief for CAD / Sketch Artist

**For:** the friend turning our vision into accurate drawings/CAD.
**Products:** Step Walnut ($99, minimalist) and Step Obsidian ($109, gamer RGB). Same body, different materials/lighting.

---

## 1. The vision in one paragraph

A three-tier "stepped" desktop wireless charging stand with dedicated zones for phone, earbuds, and watch. The footprint target is 165 × 100 mm, with the exact exterior shape still TBD by the owner; proportions may adjust within ±10% so long as the structure stays clearly three-tier and the internal engineering rules below are preserved. Walnut should read like a warm sculpted wood desk object with a single soft white status LED through a front light pipe. Obsidian should read as continuous matte carbon-fiber with recessed RGB glow *lines* along both sides (glow only, never visible LED dots).

## 2. Overall envelope (target dimensions — adjust ±10% for proportions; exact exterior shape TBD)

| Dimension | Target |
|---|---|
| Footprint (W × D) | 165 × 100 mm |
| Base top surface (Z) | 3 mm above desk |
| Riser top surface (Z) | 25 mm above desk *(3 + 22)* |
| Step 1 / Zone 1 top surface (Z) | 40 mm above desk *(25 + 15)* |
| Step 2 / Zone 2 top surface (Z) | 55 mm above desk *(40 + 15)* |
| Step 3 / Zone 3 top surface (Z) | 70 mm above desk *(55 + 15)* |
| Vertical stack breakdown | 3 mm base + 22 mm riser + 15 mm + 15 mm + 15 mm |
| Total height | 70 mm |
| Step 1 / Zone 1 | Phone, Qi2 20W |
| Step 2 / Zone 2 | Buds or second phone, Qi up to 15W |
| Step 3 / Zone 3 | Watch, 5W |
| Step 3 setback | 20 mm in Y from the front edge of Steps 1–2 |
| Corner radii | 6–8 mm (soft, premium) |
| Split line | Horizontal, 8 mm above desk — base shell + top shell |

## 3. Hard engineering constraints (non-negotiable)

1. **Wall thickness 2.4 mm** everywhere, EXCEPT directly above each charging coil: **1.2–1.5 mm max** (thicker kills charging).
2. **Coil pockets:** cylindrical recesses under each pad surface, sized from the measured phone coil, earbuds coil, and watch coil modules + **0.3 mm clearance** all around. Each coil must sit flush against the underside of its charging surface.
3. **4× M3 heat-set insert bosses** in the base shell (Ø7.2 mm hole for M3 insert, boss Ø10 mm, near corners); matching screw counterbores through the top shell from below — **no visible screws from top or sides**.
4. **Rear USB-C recesses:** 2× rear USB-C ports total — USB-C PD **IN** at X=40 and USB-C **OUT** at X=130 (15W class). The **IN** port must be visually differentiated (deeper recess or engraved **IN** marking). Size the rear recess / strain channel around the USB-C input plug overmold and bend relief rather than a barrel plug.
5. **Thermistor channel:** 3 mm wide groove from the phone coil pocket to the main board bay.
6. **Board standoffs:** 2 mm tall pins/clips for the PD input trigger board, the output trigger board, and MCU board (dimensions after we measure — see §5).
7. **Walnut only:** Ø3.2 mm light-pipe hole on the front face, centered, **14 mm above desk**, fully owned by the **top shell** so it sits clearly above the 8 mm split line.
8. **Obsidian only:** recessed groove on each side face, 5 mm tall × 3 mm deep × ~140 mm long, positioned 6 mm above desk, to hold a press-fit diffuser bar over a **60 LED/m WS2812B strip**. Size the groove for **8 LEDs per side (16 total)** with ~**16.7 mm pitch**, about **116.7 mm first-to-last LED center span**, and about **133 mm end-to-end strip cut length per side**, plus wire relief; diffuser sits flush or up to 0.5 mm proud. Wire pass-through from each groove into the base cavity.
9. **Hidden venting:** add concealed vent slots in the base shell for coil thermal relief, but keep them invisible from normal top/side views.
10. **Optional ballast:** include a base-shell cavity / steel plate pocket option for anti-slip heft without changing the exterior silhouette.
11. **4× feet recesses** on the bottom: Ø10 mm × 1 mm deep (for silicone bumpers).
12. **Shared board bay:** both Step models use a **Digispark-style ATtiny85 USB board** plus easy-connect power hardware. The shared enclosure geometry must fit the measured board footprint/height from §5 along with the screw-terminal distribution parts.
13. Design for FDM printing: no overhangs >50° without a chamfer, flat surfaces face up on the print bed, both shells printable without supports if possible.

## 4. Deliverables we need from you

- Dimensioned drawings (top, front, side, section through all three coil pockets) — hand-drawn with real numbers is fine
- If doing CAD: STEP + STL of both shells, per model variant
- Exploded view sketch showing stack order: base → boards → coils → top shell

## 5. Component measurement checklist (WE fill this in before you finalize)

Measure with calipers — do not trust seller datasheets. All in mm.

| Component | Measure | Value |
|---|---|---|
| Phone Qi TX coil | Coil outer Ø, thickness, PCB L×W×H if attached, cable exit position | ___ |
| Buds TX coil | Same | ___ |
| Watch TX coil | Same + cradle / magnet carrier dimensions if separate | ___ |
| PD input trigger board | L × W × H, tallest component height, negotiated-voltage setting access, mounting hole positions/Ø | ___ |
| USB-C PD output trigger board | L × W × H, tallest component height, USB-C port overhang, mounting hole positions/Ø | ___ |
| Digispark-style ATtiny85 USB board | L × W × H, USB overhang, mounting method | ___ |
| Panel-mount USB-C input receptacle | Body L × W × H, panel cutout needs, rear clearance | ___ |
| Power-distribution PCB / block | L × W × H, terminal pitch, mounting holes/clearance | ___ |
| 12V / 5V screw-terminal buck converters | L × W × H, terminal overhang, adjustment-pot access | ___ |
| LED strip (Obsidian) | Width, thickness, LED pitch, cut lengths | ___ |
| Light pipe (Walnut) | Ø, length | ___ |
| Thermistor | Bead Ø, lead length | ___ |
| M3 heat-set insert | OD, length | ___ |
| USB-C input cable plug | Overmold W × H + cable exit angle / bend relief (for the rear recess clearance) | ___ |
| 65W GaN brick | Brick L × W × H, USB-C port-face clearance on the brick body | ___ |

**Rule: no coil pocket, boss, standoff, or shared board-bay dimension gets finalized until this table is filled with caliper measurements from the actual parts on our bench.**

## 6. Look & feel references

- Walnut: warm, soft-edged, like a sculpted wooden pebble with steps. Think high-end desk accessory, not gadget.
- Obsidian: sharp but not aggressive; continuous CF weave; when RGB is on, two clean underglow-style light lines; when off, it should look completely minimal.
- Nothing on the top surfaces except the device pads (subtle 0.4 mm raised locating ring around each pad zone is welcome).

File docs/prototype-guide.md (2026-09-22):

# Epitome Step — Prototype Guide (Sept 2026 planning estimates)

## Prototype target

- Build: **2 total prototypes** (1 Step Walnut + 1 Step Obsidian).
- Purpose: geometry, thermal behavior, firmware behavior, and demand-content capture.

## Before printing

1. Place measurement order (~$35, one of each module).
2. Record caliper dimensions in `docs/design-brief-step.md`.
3. Finalize CAD production files.
4. Validate Zone 2 second-device landing geometry before STL freeze.

## Print/material baseline

| Model | Base | Top | Notes |
|---|---|---|---|
| Walnut | Black PETG | Wood-PLA | Sand + Danish oil on top shell |
| Obsidian | CF-PETG | CF-PETG | Hardened steel nozzle required |

## Electronics/FW split

- Walnut: Digispark-style ATtiny85, white status LED.
- Obsidian: Digispark-style ATtiny85 + WS2812B RGB (8 LEDs per side).
- Shared charging config: 20W phone + up-to-15W Zone 2 + 5W watch + 15W USB-C output.

## Validation gates

- Charge compatibility and thermal soak (single-zone and dual-zone)
- Thermal cutoff/recovery
- Obsidian RGB modes + OFF persistence
- Full-load behavior with firmware low-power profile on Zone 2 when all zones are active
- USB-C 15W output stability

Detailed per-model QC: `docs/technical-readouts/`.

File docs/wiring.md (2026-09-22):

# Epitome Step — Wiring Guide

---

## Easy-connect power path

```
65W GaN brick
        │
        ▼
USB-C PD input receptacle (rear X=40, Z=15)
        │
        ▼
PD input trigger board (20V negotiated output)
        │
        ▼
20V screw-terminal distribution PCB / block
        ├──→ USB-C PD 15W output trigger board            [screw terminal feed]
        ├──→ 12V screw-terminal buck converter input
        │       └──→ 12V distribution terminals ──→ Zone 1 Qi2 TX   [J1]
        │                                          └──→ Zone 2 Qi TX [J2]
        └──→ 5V screw-terminal buck converter input
                └──→ 5V distribution terminals ──→ Zone 3 watch TX   [J3]
                                                   ├──→ Digispark ATtiny85 [J4]
                                                   └──→ Lighting      [J5/J6]
```

All power branches terminate in screw terminals or pre-crimped JST-XH pigtails.

---

## Zone 1 — Phone (Qi2 20W)

| Wire | From | To |
|---|---|---|
| 12V power | 12V distribution terminals via J1 | Qi2 TX VIN |
| GND | 12V distribution terminals via J1 | Qi2 TX GND |
| Detect | Qi2 TX STAT via J7 (orange) | Digispark ATtiny85 PB1 |

- Polyfuse remains in-line on the 12V feed.

---

## Zone 2 — Buds or second phone (up to 15W)

| Wire | From | To |
|---|---|---|
| 12V power | 12V distribution terminals via J2 | Qi TX VIN |
| GND | 12V distribution terminals via J2 | Qi TX GND |
| Detect | Qi TX STAT via J8 (orange) | Digispark ATtiny85 PB2 |

- Polyfuse remains in-line on the 12V feed.

---

## Zone 3 — Watch (5W)

| Wire | From | To |
|---|---|---|
| 5V power | 5V distribution terminals via J3 | Watch TX VIN |
| GND | 5V distribution terminals via J3 | Watch TX GND |
| Detect | Watch TX STAT via J9 (orange) | Digispark ATtiny85 PB3 |

- Generic watch coil is not Apple Watch-compatible unless MFi hardware is selected.

---

## USB-C ports

| Port / stage | Protection / board | From | To |
|---|---|---|---|
| USB-C PD input stage | Panel-mount USB-C receptacle + PD input trigger board | 65W GaN brick | 20V distribution rail |
| USB-C output (15W) | ~1A hold polyfuse + TVS + 15W trigger board | 20V distribution block | Rear output receptacle |

Rear panel uses **2× panel-mount USB-C**: **IN at X=40**, **OUT at X=130**.

---

## Digispark ATtiny85 connections summary

| Pin | Net | Notes |
|---|---|---|
| PB0 | LED DATA out | Both models |
| PB1 | Zone 1 detect in | HIGH = phone present |
| PB2 | Zone 2 detect in | HIGH = zone active |
| PB3 | Zone 3 detect in | HIGH = watch zone active |
| PB4 | **Obsidian only:** mode button in | Active LOW, internal pull-up enabled |

---

## JST assignments

| Connector | Colour | Signal |
|---|---|---|
| J1 | Red/Black | 12V to Zone 1 Qi2 TX |
| J2 | Red/Black | 12V to Zone 2 Qi TX |
| J3 | Red/Black | 5V to Zone 3 watch TX |
| J4 | Red/Black | 5V to Digispark ATtiny85 |
| J5 | Red/Black | 5V to lighting |
| J6 | White | LED DATA line |
| J7 | Orange/Black | Zone 1 detect to PB1 |
| J8 | Orange/Black | Zone 2 detect to PB2 |
| J9 | Orange/Black | Zone 3 detect to PB3 |
| J10 | Grey | **Obsidian only:** mode button to PB4 |

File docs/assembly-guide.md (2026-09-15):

# Epitome Step — Beginner Assembly Guide (No-Solder)

This scaffold is for a first-time builder. The target build method is plug-in JST and screw-terminal only.

## Tools

- Small screwdriver
- Wire stripper
- Multimeter
- Heat gun *(for solder-seal fallback + heat-set insert work)*
- Thermal epoxy

## Before you start

- **Unit #1 is a learning unit.** Photograph every step, every wire label, and every finished subassembly.
- Fold those photos back into this guide after the first build so Units #2–#6 become paint-by-numbers.
- Read `docs/wiring.md` first and keep it open next to the bench.

## Ordered build steps

1. **Print the shells**
   - Print the current Step base and top shells for the target model.
   - Dry-fit the shells and confirm the cable exits and insert bosses are clean before electronics go in.

2. **Install heat-set inserts**
   - Practice on scrap first.
   - Install the M3 inserts square to the bosses and let the plastic cool fully before test-threading screws.

3. **Mount the power hardware**
   - Install the panel-mount USB-C input receptacle and the PD input trigger board.
   - Install the screw-terminal 20V distribution block / PCB.
   - Install both screw-terminal buck converters.
   - Leave the module outputs disconnected from the loads for now.

4. **HARD GATE — set and verify buck outputs before connecting any module**
   - Power only the USB-C input receptacle + PD input trigger board + distribution block + buck converters.
   - Confirm the PD input trigger is negotiating the intended input rail before landing any load wiring.
   - Use the multimeter to set the 12V buck to **12.0V ±0.1V**.
   - Use the multimeter to set the 5V buck to **5.0V ±0.1V**.
   - **Do not connect the Qi boards, the Digispark, or the LEDs until both outputs are verified.**

5. **Connect modules via JST per `docs/wiring.md` J1–J10**
   - Plug in the pre-crimped JST-XH pigtails for J1–J10.
   - Keep the polyfuses in-line exactly as shown in the wiring guide.
   - Use the factory JST-SM LED leads; do not solder LED pads.

6. **Polarity checklist for every screw terminal**
   - Red = **+**
   - Black = **GND**
   - Label each terminal pair with a paint pen before landing the wire.
   - Tug-test every wire after tightening.

7. **Install the Digispark-style ATtiny85 board**
   - Flash over USB in the Arduino IDE.
   - Build the correct firmware target before install:
     - `MODEL_WALNUT`
     - `MODEL_OBSIDIAN`
   - After flashing, mount the board and connect J4/J6/J7/J8/J9/J10 as applicable.

8. **Smoke test with no devices on the charger**
   - Power the unit.
   - Confirm there is no unexpected heat, smell, or flicker.
   - Confirm the expected idle light behavior for the model.

9. **Zone-by-zone charge test**
   - Test Zone 1 alone.
   - Test Zone 2 alone.
   - Test Zone 3 alone.
   - Then test combined wireless use before trying any USB-C output load.

10. **Thermal check**
    - Run a 15-minute phone charge on Zone 1 and confirm charging stays stable for the full test (no repeated dropouts).
    - Remove the phone, then **disconnect input power** before setting up the cutoff test.
    - Identify the chosen Qi TX board family's observable thermal-cutoff indicator for Batch 1 documentation: onboard status/fault LED, documented fault pin, or the exposed Zone 1 status lead if that board family uses it for cutoff state.
    - Re-apply input power with **no device charging**, set the heat gun to low, hold it roughly **15–20 cm (6–8 in)** away, and warm the NTC bead in **2–3 second sweeps** until the documented indicator flips to the thermal-cutoff state. Stop heating immediately, allow cooldown, and confirm the same indicator returns to its normal ready state.
    - Acceptance rule: **the 15-minute charging run must stay stable, and the documented board-family cutoff indicator must show both cutoff and recovery during the warm-up test.** Record which indicator was used for the unit log.

11. **Final assembly**
    - Dress the service loops.
    - Close the shell.
    - Install feet / bumpons.
    - Re-run a short final power-on check after the enclosure is closed.

## Fallback note

If a wire join is unavoidable, use a **solder-seal wire connector** and a heat gun rather than freehand soldering.

## Per-unit QA sign-off

| Unit | Model | 12V buck verified | 5V buck verified | J1–J10 polarity checked | USB flash OK | Smoke test OK | Zone 1 | Zone 2 | Zone 3 | Thermal check OK | Final closeout |
|---|---|---|---|---|---|---|---|---|---|---|---|
| 1 |  |  |  |  |  |  |  |  |  |  |  |
| 2 |  |  |  |  |  |  |  |  |  |  |  |
| 3 |  |  |  |  |  |  |  |  |  |  |  |
| 4 |  |  |  |  |  |  |  |  |  |  |  |
| 5 |  |  |  |  |  |  |  |  |  |  |  |
| 6 |  |  |  |  |  |  |  |  |  |  |  |

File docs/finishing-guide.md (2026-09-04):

# Epitome Step — Finishing Guide (Sept 2026)

## Walnut finishing (wood-PLA top shell)

Required production baseline:
1. Sand: 120 → 220 grit minimum.
2. 400-grit finishing pass is required for final customer-facing units and recommended for prototypes where visual quality is being evaluated.
3. Clean dust fully.
4. Apply Danish oil (thin coat), wipe excess.
5. Allow cure; buff lightly.

## Obsidian finishing (CF-PETG shells)

- No paint system required.
- Light deburr only where needed.
- Preserve matte carbon-weave texture.

## Visual targets

- Walnut: warm, furniture-like top shell with subtle white status LED.
- Obsidian: clean matte carbon body with flush RGB glow lines and no exposed LED dots.

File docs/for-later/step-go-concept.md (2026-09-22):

# Step Go — Travel Charging Dock (FOR LATER)

**Status:** Concept only. Reserve-gated.

## Cost model update (Sept 2026 tariffed pricing)

China-sourced electronics include 25% Section 301 tariff.

| Part | Cost |
|---|---:|
| Certified 20,000 mAh PD bank | $22.50 |
| Qi TX module | $5.63 |
| Zone 2 Qi TX module (up-to-15W class) | $5.63 |
| USB-C trigger board (15W class) | $1.50 |
| NTC + polyfuse + wiring | $2.00 |
| Controller + status LED | $2.50 |
| PETG enclosure + feet/fasteners | $6.00 |
| Packaging | $6.00 |
| **Build cost** | **~$49.38** |

Example economics at $120 target price:
- Payment processing (~2.9% + $0.30): ~$3.78
- Defect reserve (10% of build): ~$4.94
- Estimated net after fees/reserve: **~$61.90/sale**

## Notes

- Keep battery strategy as certified modular bank only.
- Keep gate policy aligned with `docs/budget-plan.md`.
- Use Outdoor Block technical readouts as durability/safety baseline patterns.

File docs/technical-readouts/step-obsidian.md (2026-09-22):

# Step Obsidian — Technical Readout

## Enclosure specification
- Same stepped geometry as Walnut.
- **Both shells:** CF-PETG (carbon-weave matte).
- Side RGB grooves with flush diffuser bars (glow lines only, no visible LED dots).
- WS2812B count target: **8 LEDs per side (16 total)** on 60 LED/m strip.
- Hardened steel nozzle required for CF-PETG.

## Electronics BOM (Sept 2026 planning estimates; tariffed where applicable)
| Item | Unit cost |
|---|---:|
| Zone 1 Qi2 magnetic TX module (China, +25%) | $5.63 |
| Zone 2 Qi TX module up-to-15W (same SKU class, China, +25%) | $5.63 |
| Watch TX coil (generic estimate, pending sourcing) | $3.50 |
| USB-C output trigger board (15W class, China, +25%) | $1.50 |
| 65W GaN brick target (China, +25%) | $9.50 |
| USB-C cables (1 input + 1 output) | $3.00 |
| Digispark-style ATtiny85 USB board + RGB/easy-connect harnessing | $9.80 |
| WS2812B strips + diffuser bars | $2.00 |
| CF-PETG enclosure + inserts/feet | $11.07 |
| Packaging (kraft box + insert) | $3.00 |
| **Build cost** | **~$54.63** |

## Firmware behavior (Digispark ATtiny85)
- RGB modes: rear-button colour cycling across documented preset colours plus OFF.
- RGB brightness is trimmed when wireless load is fully active.
- Soft cap behavior: when all zones are active, Zone 2 shifts to low-power profile.
- Thermal cutoff behavior retained through the Qi module / hardwired thermal chain.

## Unit economics
- Price: $109
- Customer-paid shipping target: ~$10.50 label
- Net per sale after fees/processing/defect reserve: **~$34–38**

## Compatibility wording constraints
- Zone 1 wording: "Qi2 magnetic charging — compatible with MagSafe-case iPhones and Qi2 Android phones."
- Zone 3 generic watch coil does **not** support Apple Watch unless an MFi-certified module is used.

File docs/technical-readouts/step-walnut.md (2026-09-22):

# Step Walnut — Technical Readout

## Enclosure specification
- Two-shell stepped enclosure.
- **Base shell:** black PETG.
- **Top shell:** wood-PLA, sanded and Danish-oiled.
- Single white status LED via 3 mm light pipe.
- Wall thickness 2.4 mm; coil window ≤1.5 mm; M3 heat-set inserts ×4.

## Electronics BOM (Sept 2026 planning estimates; tariffed where applicable)
| Item | Unit cost |
|---|---:|
| Zone 1 Qi2 magnetic TX module (China, +25%) | $5.63 |
| Zone 2 Qi TX module up-to-15W (same SKU class, China, +25%) | $5.63 |
| Watch TX coil (generic estimate, pending sourcing) | $3.50 |
| USB-C output trigger board (15W class, China, +25%) | $1.50 |
| 65W GaN brick target (China, +25%) | $9.50 |
| USB-C cables (1 input + 1 output) | $3.00 |
| Digispark-style ATtiny85 USB board + easy-connect harnessing | $7.37 |
| Enclosure + inserts/feet + oil finish | $9.50 |
| Packaging (kraft box + insert) | $3.00 |
| **Build cost** | **~$48.63** |

## Firmware behavior (Digispark ATtiny85)
- Default: steady warm-white status LED during non-night hours.
- Zone detect pulse: brief brightness pulse on newly detected device presence.
- Night mode: timer-based overnight LED-off window (approximate, no RTC alignment).
- Soft cap behavior: when all zones are active, Zone 2 shifts to low-power profile.

## Unit economics
- Price: $99
- Customer-paid shipping target: ~$10.50 label
- Net per sale after fees/processing/defect reserve: **~$30–32**

## Compatibility wording constraints
- Zone 1 wording: "Qi2 magnetic charging — compatible with MagSafe-case iPhones and Qi2 Android phones."
- Zone 3 generic watch coil does **not** support Apple Watch unless an MFi-certified module is used.

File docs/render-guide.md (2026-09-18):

# Epitome Step — Render Guide

How to run all four render scripts and use the outputs.

---

## Setup

```bash
cd scripts
pip install -r requirements.txt
```

All scripts use only standard Python + `Pillow` (PIL). No Blender, no 3D renderer, no external tools required.

---

## Scripts and outputs

### 1. `generate_render.py` — Marketing render

Produces labelled isometric renders with device silhouettes, LED glow, and zone labels.

```bash
python generate_render.py              # both models
python generate_render.py --model walnut
python generate_render.py --model obsidian
```

**Output:**
- `assets/step-walnut-render.png` — 1200 × 800 px, dark background (#111111)
- `assets/step-obsidian-render.png` — 1200 × 800 px, dark background (#0a0a0a)

**Use for:** Etsy listing secondary image, Reddit post, product page gallery.

---

### 2. `generate_image.py` — Hero product image

Clean isometric product shot. No labels, no text. Pure product photography style.

```bash
python generate_image.py              # both models
python generate_image.py --model walnut
python generate_image.py --model obsidian
```

**Output:**
- `assets/step-walnut-hero.png` — 1200 × 800 px, warm light background (#F5F0E8)
- `assets/step-obsidian-hero.png` — 1200 × 800 px, dark background (#0d0d0d)

**Use for:** Etsy listing primary image, Shopify product hero, Instagram.

---

### 3. `generate_product_sheet.py` — Product sheet

Two-panel layout: left panel is dock render with labels, right panel is spec sheet text. Fully readable at 1200 × 800 px.

```bash
python generate_product_sheet.py              # both models
python generate_product_sheet.py --model walnut
python generate_product_sheet.py --model obsidian
```

**Output:**
- `assets/step-walnut-product-sheet.png` — 1200 × 800 px
- `assets/step-obsidian-product-sheet.png` — 1200 × 800 px

**Use for:** Shopify product description, Etsy listing image 2–4, social media comparison post.

---

### 4. `generate_3d_model.py` — Technical diagrams

Engineering drawing style. Dimension arrows, zone labels, exact mm measurements.

```bash
python generate_3d_model.py
```

**Output:**
- `assets/step-technical-top.png` — 1200 × 900 px top view with dimensions
- `assets/step-technical-side.png` — 900 × 900 px side cross-section with dimensions

**Use for:** Design documentation, prototype guide, supplier communication.

---

## How to use the outputs

| Image | Platform | Purpose |
|---|---|---|
| `step-walnut-hero.png` | Etsy listing image 1, Shopify hero | Primary product shot |
| `step-walnut-render.png` | Etsy image 2, Reddit post | Labelled render showing zones |
| `step-walnut-product-sheet.png` | Etsy image 3, Shopify gallery | Spec sheet for informed buyers |
| `step-obsidian-hero.png` | Obsidian Etsy/Shopify primary | Dark product shot |
| `step-obsidian-render.png` | Reddit battlestations, Instagram | RGB glow visible |
| `step-obsidian-product-sheet.png` | Obsidian spec sheet | |
| `step-technical-top.png` | Docs, supplier PDFs | Engineering reference |
| `step-technical-side.png` | Docs, supplier PDFs | Engineering reference |

---

## Regenerating after design changes

If you change the physical dimensions in `docs/design-spec.md`, update the geometry values used directly in each script before regenerating. The scripts currently encode the same canonical layout (165 × 100 footprint; Z stack 3/25/40/55/70; Step 2 bounds 17.5–147.5; Step 3 bounds X=35–130 and Y=20–100), but they do so with script-specific variable names and literals.

- `generate_render.py` — update base/step geometry values inside `build_render()`
- `generate_image.py` — update matching geometry values inside `build_hero()`
- `generate_product_sheet.py` — update matching geometry values inside `draw_dock()`
- `generate_3d_model.py` — update view geometry and dimension labels inside `generate_top_view()` and `generate_side_view()`

Keep all four scripts aligned when dimensions change.

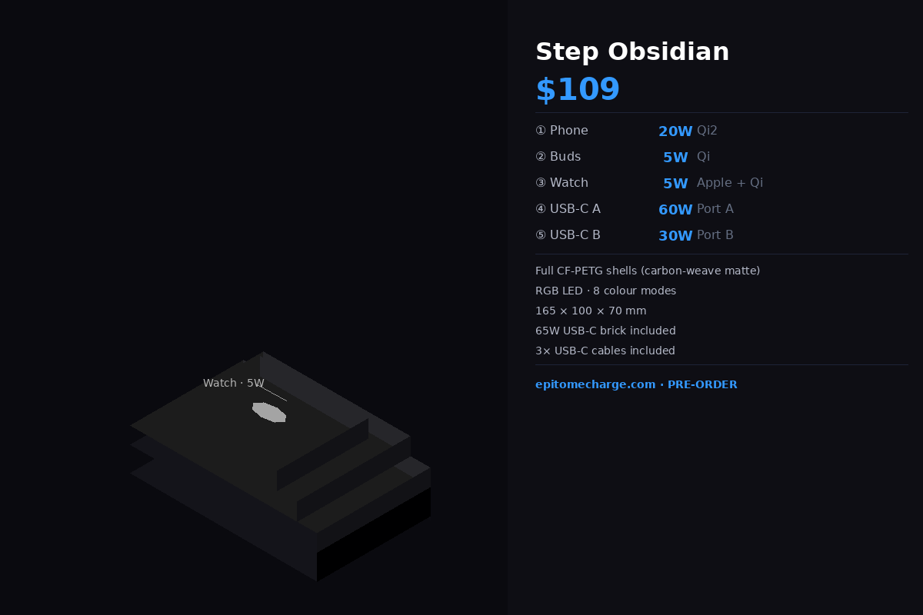
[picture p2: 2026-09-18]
assets/step-obsidian-product-sheet.png

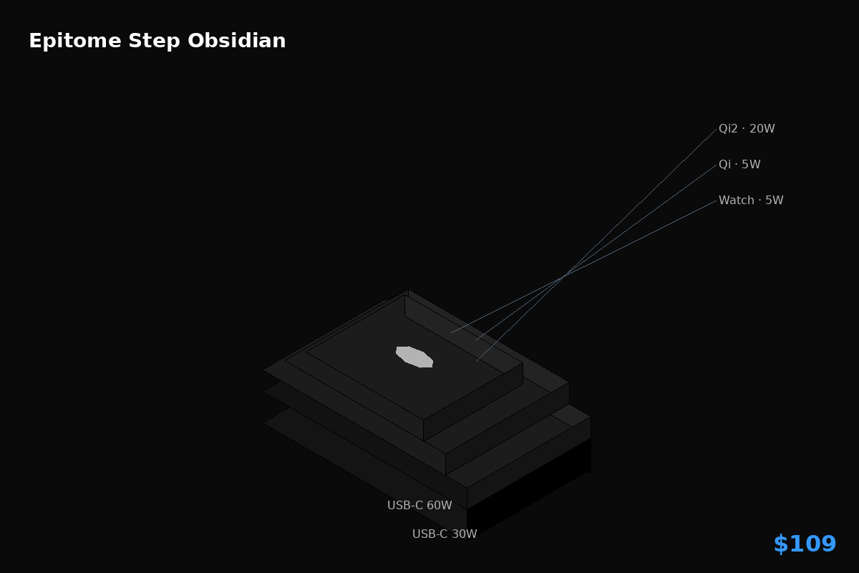
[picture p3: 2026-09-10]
assets/step-obsidian-render.png

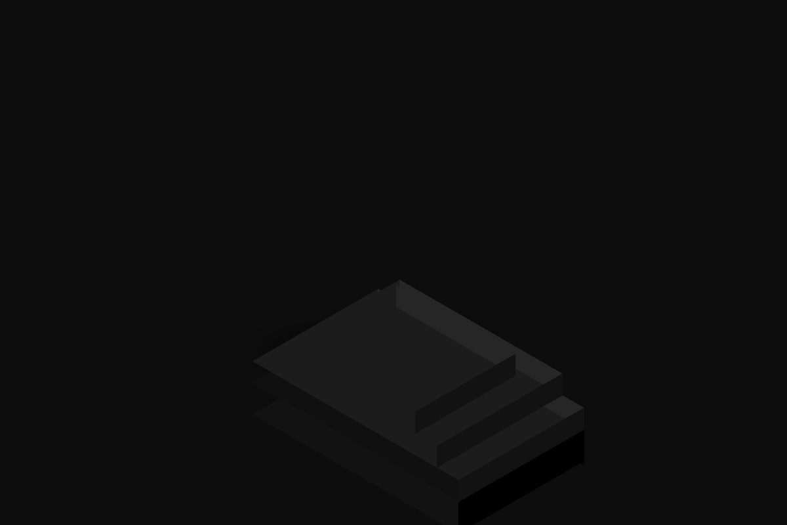
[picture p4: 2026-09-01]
assets/step-obsidian-hero.png

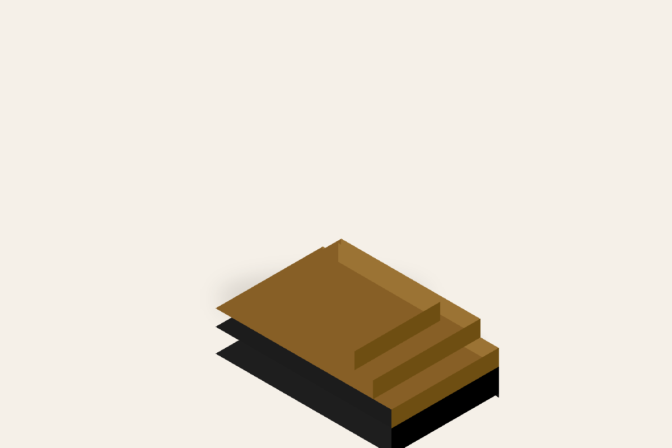
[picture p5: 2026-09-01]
assets/step-walnut-hero.png

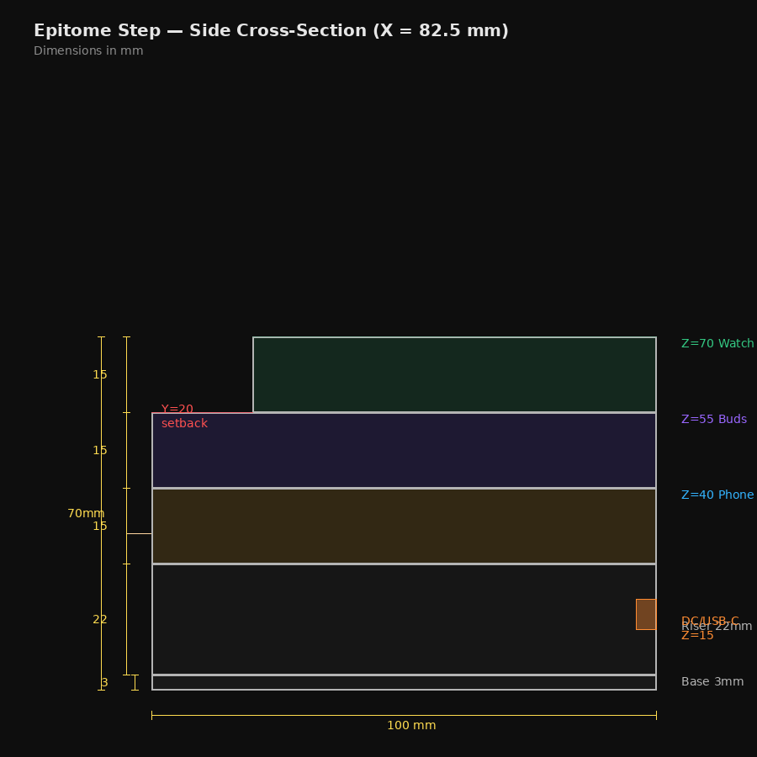
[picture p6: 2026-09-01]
assets/step-technical-side.png

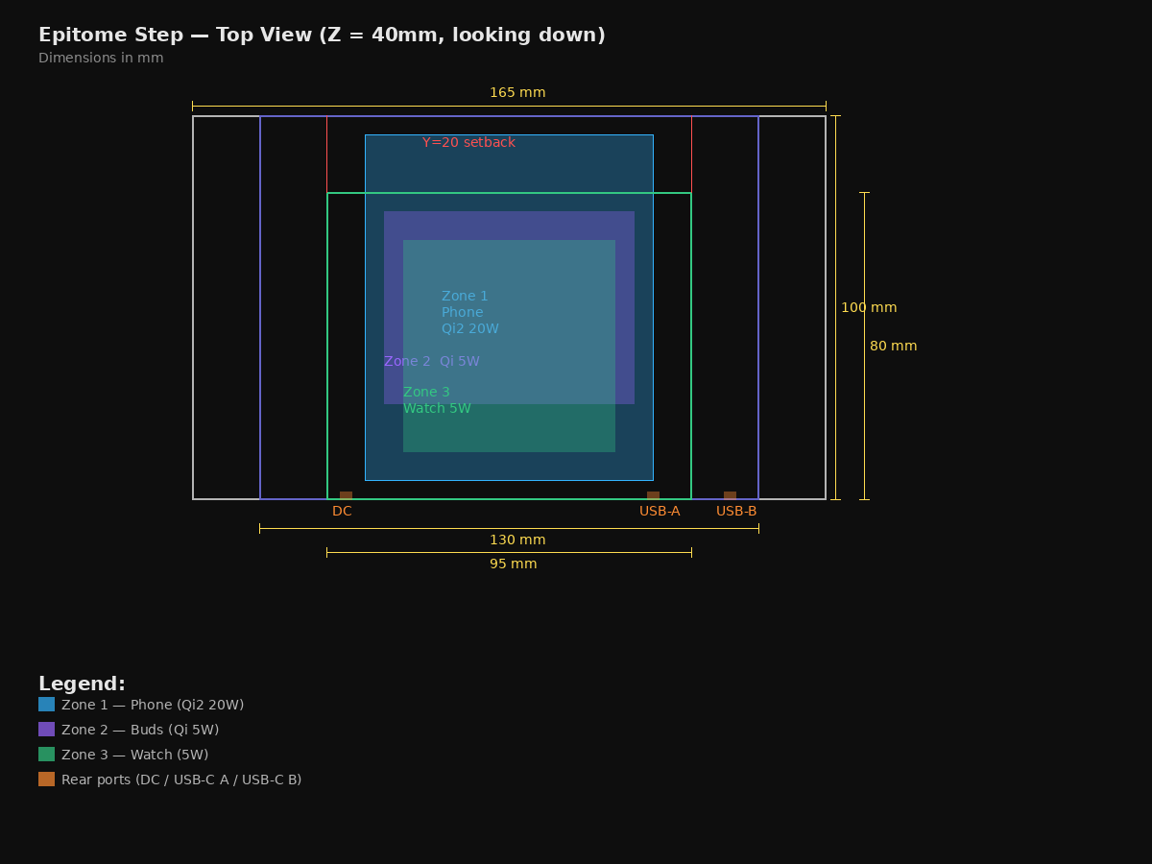
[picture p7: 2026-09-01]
assets/step-technical-top.png

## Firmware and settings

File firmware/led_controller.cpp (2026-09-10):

/**
 * Epitome Step — LED Controller Implementation
 * ATtiny85, FastLED library.
 *
 * Compile-time model selection via led_controller.h.
 * Flash MODEL_WALNUT binary to Walnut units.
 * Flash MODEL_OBSIDIAN binary to Obsidian units.
 */

#include "led_controller.h"
#include <FastLED.h>
#include <avr/io.h>
#include <avr/interrupt.h>
#include <avr/wdt.h>

// ── LED array ──────────────────────────────────────────────────────────────────
static CRGB leds[LED_COUNT];

// ── State ──────────────────────────────────────────────────────────────────────
static volatile uint32_t tick_counter = 0; // seconds since power-on (noon reference)
static volatile uint8_t  tick_pending = 0;
static uint8_t           current_brightness = LED_BRIGHTNESS;
static uint8_t           is_night = 0;
static volatile uint8_t  pulse_active = 0;
static volatile uint8_t  pulse_ticks = 0;

#ifdef MODEL_OBSIDIAN
static volatile uint8_t mode_index = 0;           // current RGB mode (0–7)
static volatile uint8_t mode_changed = 0;         // set in main loop, cleared in led_update
static volatile uint8_t button_event_pending = 0; // set in ISR, handled in led_update
#endif

// ── Forward declarations ───────────────────────────────────────────────────────
static void apply_colour(void);
static uint8_t get_brightness_cap(void);
static void check_soft_cap(void);
static void check_night_mode(uint32_t tick_value);

// ── Watchdog ISR (1 Hz tick) ───────────────────────────────────────────────────
ISR(WDT_vect) {
    led_tick();
}

// ── INT0 ISR — Obsidian mode button (PB4 → INT0 not directly, use PCINT) ───────
#ifdef MODEL_OBSIDIAN
ISR(PCINT0_vect) {
    // Only act on falling edge (button press, active LOW)
    if (!(PINB & (1 << PIN_MODE_BTN))) {
        button_event_pending = 1;
    }
}
#endif

// ── Initialisation ─────────────────────────────────────────────────────────────
void led_init(void) {
    // Configure zone detect pins as inputs with pull-up
    DDRB  &= ~((1 << PIN_ZONE1) | (1 << PIN_ZONE2) | (1 << PIN_ZONE3));
    PORTB |=  ((1 << PIN_ZONE1) | (1 << PIN_ZONE2) | (1 << PIN_ZONE3));

#ifdef MODEL_WALNUT
    // No button on Walnut
    FastLED.addLeds<WS2811, PIN_LED_DATA, RGB>(leds, LED_COUNT);
#endif

#ifdef MODEL_OBSIDIAN
    // Mode button input with pull-up
    DDRB  &= ~(1 << PIN_MODE_BTN);
    PORTB |=  (1 << PIN_MODE_BTN);

    // Pin change interrupt on PB4 for mode button
    GIMSK  |= (1 << PCIE);
    PCMSK  |= (1 << PCINT4);

    FastLED.addLeds<WS2812B, PIN_LED_DATA, GRB>(leds, LED_COUNT);
#endif

    FastLED.setBrightness(LED_BRIGHTNESS);

    // Watchdog timer for 1-second ticks
    cli();
    MCUSR  &= ~(1 << WDRF);
    WDTCR  |=  (1 << WDCE) | (1 << WDE);
    WDTCR   =  (1 << WDIE) | (1 << WDP2) | (1 << WDP1); // ~1 second
    sei();

    apply_colour();
    FastLED.show();
}

// ── Tick handler (called from WDT ISR, once per second) ───────────────────────
void led_tick(void) {
    tick_counter++;
    if (tick_counter >= TICKS_PER_DAY) {
        tick_counter = 0;  // roll over at midnight+12h
    }
    tick_pending = 1;

    if (pulse_active && pulse_ticks > 0) {
        pulse_ticks--;
        if (pulse_ticks == 0) {
            pulse_active = 0;
        }
    }
}

// ── Zone pulse ─────────────────────────────────────────────────────────────────
void led_pulse_zone(uint8_t zone) {
    (void)zone;  // same pulse for all zones
    if (is_night) return;
    pulse_active = 1;
    pulse_ticks  = 2;  // brief pulse window, cleared by the WDT tick path
    current_brightness = get_brightness_cap();
}

// ── Obsidian: cycle mode ───────────────────────────────────────────────────────
#ifdef MODEL_OBSIDIAN
void led_next_mode(void) {
    mode_index = (mode_index + 1) % RGB_MODE_COUNT;
    mode_changed = 1;
}
#endif

// ── Main update loop (call as frequently as possible from main loop) ───────────
void led_update(void) {
    uint8_t leds_dirty = 0;
    static uint8_t last_brightness = 0xFF;

    uint32_t tick_value = 0;
    uint8_t has_tick_update = 0;
    uint8_t sreg = SREG;
    cli();
    if (tick_pending) {
        tick_value = tick_counter;
        tick_pending = 0;
        has_tick_update = 1;
    }
    SREG = sreg;

    if (has_tick_update) {
        check_night_mode(tick_value);
    }

    // Check zone detect pins for device presence
    uint8_t z1 = (PINB >> PIN_ZONE1) & 1;
    uint8_t z2 = (PINB >> PIN_ZONE2) & 1;
    uint8_t z3 = (PINB >> PIN_ZONE3) & 1;

    // Pulse on newly detected device (simple edge: could add debounce if needed)
    static uint8_t last_z1 = 0, last_z2 = 0, last_z3 = 0;
    if (z1 && !last_z1) led_pulse_zone(1);
    if (z2 && !last_z2) led_pulse_zone(2);
    if (z3 && !last_z3) led_pulse_zone(3);
    last_z1 = z1; last_z2 = z2; last_z3 = z3;

#ifdef MODEL_OBSIDIAN
    static uint8_t button_lockout = 0;
    static uint8_t release_samples = 0;  // ~150 ms with the Arduino loop's 50 ms delay
    uint8_t button_pressed = !(PINB & (1 << PIN_MODE_BTN));
    uint8_t button_event = 0;

    sreg = SREG;
    cli();
    button_event = button_event_pending;
    button_event_pending = 0;
    SREG = sreg;

    if (button_lockout) {
        if (button_pressed) {
            release_samples = 0;
        } else if (release_samples < 3) {
            release_samples++;
        }

        if (release_samples >= 3) {
            button_lockout = 0;
            release_samples = 0;
        }
    }

    if (button_event && button_pressed && !button_lockout) {
        led_next_mode();
        button_lockout = 1;
        release_samples = 0;
    }

    if (mode_changed) {
        mode_changed = 0;
        apply_colour();
        leds_dirty = 1;
    }
#endif

    check_soft_cap();
    if (current_brightness != last_brightness) {
        last_brightness = current_brightness;
        leds_dirty = 1;
    }

    if (leds_dirty) {
        FastLED.setBrightness(current_brightness);
        FastLED.show();
    }
}

// ── Colour application ─────────────────────────────────────────────────────────
static void apply_colour(void) {
#ifdef MODEL_WALNUT
    for (uint8_t i = 0; i < LED_COUNT; i++) {
        leds[i] = CRGB(WARM_R, WARM_G, WARM_B);
    }
#endif

#ifdef MODEL_OBSIDIAN
    uint8_t r = RGB_MODES[mode_index][0];
    uint8_t g = RGB_MODES[mode_index][1];
    uint8_t b = RGB_MODES[mode_index][2];
    for (uint8_t i = 0; i < LED_COUNT; i++) {
        leds[i] = CRGB(r, g, b);
    }
#endif
}

// ── Night mode check ───────────────────────────────────────────────────────────
static void check_night_mode(uint32_t tick_value) {
    uint8_t was_night = is_night;

    // Night window: tick_counter [23:00, 07:00 next day) using the noon-based day counter.
    if (tick_value >= NIGHT_START_TICK && tick_value < NIGHT_END_TICK) {
        is_night = 1;
    } else {
        is_night = 0;
    }

    if (is_night != was_night) {
        current_brightness = is_night ? 0 : get_brightness_cap();
    }
}

// ── Soft cap check ─────────────────────────────────────────────────────────────
static void check_soft_cap(void) {
    if (is_night) {
        current_brightness = 0;
    } else if (!pulse_active) {
        current_brightness = get_brightness_cap();
    }
}

static uint8_t get_brightness_cap(void) {
    if (is_night) return 0;

    uint8_t z1 = (PINB >> PIN_ZONE1) & 1;
    uint8_t z2 = (PINB >> PIN_ZONE2) & 1;
    uint8_t z3 = (PINB >> PIN_ZONE3) & 1;

    // Estimated wireless draw: zone1=20W zone2=5W zone3=5W = 30W max wireless
    // USB-C always assumed present. Dim LEDs if all three zones active (max wireless load).
    uint8_t total_wireless = (z1 * 20) + (z2 * 5) + (z3 * 5);
    return (total_wireless >= 30) ? LED_DIM_CAP : LED_BRIGHTNESS;
}

// ── Arduino-style entry points (if building with Arduino IDE) ─────────────────
#ifdef ARDUINO
void setup(void) {
    led_init();
}

void loop(void) {
    led_update();
    // Delay to avoid hammering FastLED.show() — 50 ms (20 Hz)
    delay(50);
}
#endif

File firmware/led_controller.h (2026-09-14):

/**
 * Epitome Step — LED Controller
 * ATtiny85 firmware for both Walnut and Obsidian models.
 *
 * Select model at compile time:
 *   #define MODEL_WALNUT    — WS2811, warm white, no button
 *   #define MODEL_OBSIDIAN  — WS2812B, RGB modes, rear button on PB4
 *
 * One of the two must be defined. Compile and flash separately for each model.
 */

#ifndef LED_CONTROLLER_H
#define LED_CONTROLLER_H

#include <stdint.h>

// ── Model selection ────────────────────────────────────────────────────────────
// Uncomment exactly ONE of these before flashing:
#define MODEL_WALNUT
// #define MODEL_OBSIDIAN

#if defined(MODEL_WALNUT) && defined(MODEL_OBSIDIAN)
  #error "Define MODEL_WALNUT or MODEL_OBSIDIAN — not both."
#endif
#if !defined(MODEL_WALNUT) && !defined(MODEL_OBSIDIAN)
  #error "Define MODEL_WALNUT or MODEL_OBSIDIAN before compiling."
#endif

// ── Pin assignments ────────────────────────────────────────────────────────────
#define PIN_LED_DATA    0  // PB0 — WS2811 / WS2812B data out
#define PIN_ZONE1       1  // PB1 — Zone 1 detect (HIGH = phone present)
#define PIN_ZONE2       2  // PB2 — Zone 2 detect (HIGH = buds present)
#define PIN_ZONE3       3  // PB3 — Zone 3 detect (HIGH = watch present)
#define PIN_MODE_BTN    4  // PB4 — Obsidian only: RGB mode button (active LOW)

// ── LED config for the selected Step variant ───────────────────────────────────
#if defined(MODEL_WALNUT)
  // Walnut drives a single white status LED through the front light pipe.
  #define LED_COUNT       1
#elif defined(MODEL_OBSIDIAN)
  // Obsidian uses two side glow lines: 8 LEDs per side on 60 LED/m strip = 16 total.
  #define LED_COUNT       16
#else
  // Fallback for tooling/readability only; normal builds are rejected by the model guard above.
  #define LED_COUNT       1
#endif

#define LED_BRIGHTNESS  200  // 0–255 (daytime default)
#define LED_DIM_CAP     80   // brightness when soft power cap active

// ── Night mode ─────────────────────────────────────────────────────────────────
// Timer-based: 1 tick/sec via WDT. Initialises at 12:00 (noon).
// Night = 23:00 – 07:00 next day (8 hours off). 86400 ticks/day.
#define TICKS_PER_DAY    86400UL
#define NIGHT_START_TICK 39600UL  // 11 * 3600 ticks from noon = 23:00
#define NIGHT_END_TICK   68400UL  // 19 * 3600 ticks from noon = 07:00 next day

// ── Walnut model ───────────────────────────────────────────────────────────────
#ifdef MODEL_WALNUT
  // Warm white only (#FFD6A0)
  #define WARM_R  255
  #define WARM_G  214
  #define WARM_B  160
#endif

// ── Obsidian model ─────────────────────────────────────────────────────────────
#ifdef MODEL_OBSIDIAN
  #define RGB_MODE_COUNT  8
  // Modes: 0=Blue 1=Purple 2=Green 3=Red 4=Cyan 5=Yellow 6=White 7=Off
  // Stored as {R, G, B} triples
  static const uint8_t RGB_MODES[8][3] = {
    {  51, 153, 255},  // 0 Blue
    { 153,  51, 255},  // 1 Purple
    {  51, 204, 102},  // 2 Green
    { 255,  51,  51},  // 3 Red
    {   0, 255, 255},  // 4 Cyan
    { 255, 255,   0},  // 5 Yellow
    { 255, 255, 255},  // 6 White
    {   0,   0,   0},  // 7 Off
  };
#endif

// ── Public API ─────────────────────────────────────────────────────────────────
void led_init(void);
void led_update(void);
void led_pulse_zone(uint8_t zone);   // zone: 1, 2, or 3
void led_tick(void);                 // call once per second from WDT ISR

#ifdef MODEL_OBSIDIAN
void led_next_mode(void);            // cycle to next RGB mode (called from button ISR)
#endif

#endif /* LED_CONTROLLER_H */

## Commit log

2026-07-20 Initial commit: full project documentation, BOM, wiring, app spec, and layout diagram
2026-07-20 feat: add dock render and LED controller docs
2026-07-20 chore: polish render script and wiring notes
2026-07-20 Apply all 37+ queued changes: internal PSU, tiered enclosure, WS2812B LED bar, ambient light sensor, USB-A port, MagSafe magnets, INA3221, smart app features, packaging docs, color variants, updated 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
2026-07-20 Address code review feedback: clarify sin8 stub comment, fix pulse cycle comment, fix BOM PSU model, add thermal pad clarification, refactor variant color keys in render script, add BOM cost basis ex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
    [led_controller.cpp, led_controller.h]
2026-07-21 Update all docs to Quad-Dock: rename, Arc enclosure, ESP32-C3, new spec files
2026-07-21 chore: add generated assets (3D model, render, export files)
    [quad-dock-base.stl, quad-dock-full.step, quad-dock-full.stl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]
2026-07-21 ci: improve fallback dependency install flow
2026-07-21 ci: simplify branch flow and enforce core fallback installs
2026-07-21 ci: clarify push retry control flow
2026-07-21 chore: regenerate assets [skip ci]
    [quad-dock-full.step, quad-dock-top-plate.dxf]
2026-07-21 Changes before error encountered
    Agent-Logs-Url: https://github.com/GJATHASEnterprises/quad-device-dock/sessions/6b78c61f-03a6-4d5f-a337-ff65b52c2db3
2026-07-21 feat: complete rewrite of generate_render.py and generate_3d_model.py per spec
    generate_render.py:
    - Resolution 3200×2133, 192 samples (was 2400×1600 / 128)
    - Zone 1 & 2 Y positions corrected to 57.50mm (was 60mm)
    - Zone 1 & 3 CX fixed to −20mm from centre (front-width reference)
    - Camera zoomed out: (−0.55, −0.55, 0.45), 85mm telephoto lens
    - 4-light Apple-style rig: key 800W, fill 300W, rim 200W, top-bounce 150W
    - World strength 1.0 (studio white)
    - TOP_T = 1.5mm, FOOT_INSET = 15mm
    generate_3d_model.py:
    - TOP_THICK = 1.50mm (was 2.0mm)
    - Zone 1 & 2 pockets changed from circles to rounded rectangles (80×55 R10 / 65×55 R10)
    - Zone 3 teardrop: proper cylinder 50×12mm + cone 50→1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
    [quad-dock-base-interior.stl, quad-dock-full-assembly.stl, quad-dock-full.step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]
2026-07-22 chore: regenerate manufacturing files and investor render
    [quad-dock-full.step]
2026-07-22 feat: apply definitive coordinate spec across docs and generators
    [quad-dock-base-interior.stl, quad-dock-base.stl, quad-dock-full-assembly.stl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]
2026-07-22 fix: replace all boolean operations with direct geometry construction in generate_3d_model.py
    [quad-dock-base-interior.stl, quad-dock-base.stl, quad-dock-full-assembly.stl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]
2026-07-22 refactor: address code review — named constants, remove unused function, improve docstrings
    [quad-dock-top-plate.dxf]
2026-07-22 chore: regenerate all manufacturing files - clean build, zero warnings
    [quad-dock-top-plate.dxf]
2026-07-22 chore: high quality investor render - 512 samples 4800x3200
2026-07-22 chore: tighten scene cleanup and radius clamp warning
2026-07-23 chore: high quality render - 512 samples 4800x3200
2026-07-23 feat: rewrite generate_product_sheet.py — comprehensive 6-panel investor product sheet at 7200×5400 dpi=300
2026-07-23 fix: address code review feedback — type hints, unused variable, simplified expression
2026-07-23 Fix layout and add missing features to generate_product_sheet.py
    - CHANGE 1: Separate Zone 1 (cy=60) and Zone 2 (cy=88) in draw_top_view
    and draw_perspective_view to fix overlap; update callout anchors and
    Y grid lines accordingly
    - CHANGE 2: Add laptop groove silicone guide walls and USB-C port indicator
    - CHANGE 3: Add phone silhouette in Zone 1 and AirPods case in Zone 2
    - CHANGE 4: Replace broken LED bar with correctly-clipped WS2812B bar
    - CHANGE 5: Improve etched labels (shadow pass, larger font, gold Quad-Dock)
    - CHANGE 6: Replace minimal IEC stub with full socket housing + coiled cord
2026-07-23 Fix zone overlap: widen dock illustration and reposition all zones
    - Introduce ILL_FHW=100 / ILL_RHW=120 illustration-only constants inside
    draw_top_view so the body is wider in the top view without touching the
    physical-spec globals FW/RW used by other views.
    - Replace _trapezoid_pts() with ill_pts (200mm front / 240mm rear) for the
    body and plate patches.
    - Zone 1 (Phone): centre X=-45, Y=70 — spans X=-85 to X=-5 (no overlap)
    - Zone 2 (Buds): centre X=+45, Y=70 — spans X=+12.5 to X=+77.5
    - Zone 3 (Watch): centre X=-30, Y=225
    - Zone 4 (Laptop): X=+44..+66, Y=288..300
    - Rewrite LED bar to fill full 200mm front width with 4×50mm equal segments
    - Update M3 screw holes, PCB ghost ou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
2026-08-02 Add Zone 5 iPad/Phone groove, night mode, IEC cable bundle, warranty card — full 5-zone spec
2026-08-02 Regenerate product sheet — 5-zone layout
2026-08-03 docs: massively expand design electronics and wiring references
2026-08-04 Update BOM: add 15-unit cost column, 3D printed enclosure for Batch 1, packaging fully itemised
2026-08-10 Rename product to Epitome Penta
    [epitome-penta-base-interior.stl, epitome-penta-base.stl, epitome-penta-full-assembly.stl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]
2026-08-10 docs: widen enclosure to 146/156mm and update Zone 5 X to +66
2026-08-12 Redesign: stepped centre platform with side slots for laptop and iPad
2026-08-12 Update BOM for stepped centre platform redesign
2026-08-12 Add printable HTML product sheet
2026-08-14 Full redesign update: captive cables, universal watch charging, dual SKUs, all fixes
2026-08-20 BOM cost reduction + 3-step tapered centre platform
2026-08-20 Refine BOM/prototype cost notes after review
2026-08-21 Update BOM, enclosure spec, and parts links for compact on-edge slot design
2026-08-21 docs: full consistency pass — align all docs to current spec (August 2026)
2026-08-24 docs: revise enclosure layout and costs
2026-08-24 docs: clarify prototype step height
2026-08-25 Update visual generation scripts for compact rectangular dock design
    [epitome-penta-base-interior.stl, epitome-penta-base.stl, epitome-penta-full-assembly.stl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]
2026-08-25 Sync all files to final Penta Dock spec (190W, Qi2, 45W Zone 5, no ESP32/INA3221)
2026-08-25 Fix code review issues: thermistor 5V, deduplicate ATtiny85 bullets, update shelved doc titles
2026-08-26 fix geometry orientation, placement coordinates, and related diagrams/docs
    [penta-dock-base-interior.stl, penta-dock-full-assembly.stl, penta-dock-top-plate.dxf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]
2026-08-28 fix: Zone 2 dish 90x70mm, tablet wall 80mm, cost updates, script rewrites
2026-08-31 Rebrand entire repository: Penta Dock → Step
    - Rewrite all 14 docs for Step (3-zone wireless stand, walnut+ABS, $89)
    - Rewrite all 4 scripts for Step geometry and branding
    - Remove all old Penta Dock assets
    - Generate new Step assets (render, hero, product sheet, DXF)
    - Update README for Step
    [epitome-penta-base-interior.stl, epitome-penta-base.stl, epitome-penta-full-assembly.stl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]
2026-09-01 feat: complete repository rebuild for Epitome brand — Step Walnut + Step Obsidian
    - Rewrite README.md for Epitome brand, both models, both prices
    - Rewrite all 20 docs/ files (design-spec, electronics, bom, enclosure, wiring,
    component-positions, layout-diagram, compatibility, firmware-notes, finishing-guide,
    prototype-guide, packaging, parts-tools-links, marketability, uvp, pre-order-page,
    production-roadmap, app-spec, product-sheet.html, render-guide)
    - Rewrite all 4 scripts to produce dual outputs (walnut + obsidian)
    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
2026-09-01 Add Step Go travel dock concept (for-later): safety architecture, BOM, $120 unit economics, go/no-go criteria
2026-09-01 Add Outdoor Block concept spec (for-later): IP67 target, zone interlock, BOM, go/no-go gates
2026-09-03 Replace old visuals with technical readouts
    [step-top-view.dxf]
2026-09-03 Add design brief for CAD/sketch collaborator: dimensions, constraints, measurement checklist
2026-09-10 Add Upwork job post for CAD production files with scope, milestones, and screening notes
2026-09-10 fix firmware and asset generation issues
    [led_controller.cpp, led_controller.h]
2026-09-10 refine firmware button debounce
2026-09-10 fix watchdog tick race
    [led_controller.cpp]
2026-09-10 synchronize button event handling
2026-09-10 fix: make LED_COUNT model-specific branches exclusive
    [led_controller.h]
2026-09-10 chore: simplify LED_COUNT validation logic
2026-09-10 chore: add safe LED_COUNT fallback comment
2026-09-10 docs: clarify Step height and LED groove specs
2026-09-10 docs: resolve remaining CAD brief review notes
2026-09-15 Clarify USB-C input stage wording
2026-09-15 Document 12V buck bench verification note
2026-09-15 Clarify BOM input hardware comparison
2026-09-15 Correct BOM USB-C input delta wording
2026-09-15 Align Step brick and cable wording
2026-09-15 Polish Step packaging cable copy
2026-09-15 Align Step USB-C port fuse sizing
2026-09-15 Refine Step BOM and fuse notes
2026-09-15 Tighten Step Port A fuse rating
2026-09-15 Document Step USB-C fuse sizing rationale
2026-09-15 Restate Step BOM input hardware totals
2026-09-15 Clarify Step USB-C packaging and BOM notes
